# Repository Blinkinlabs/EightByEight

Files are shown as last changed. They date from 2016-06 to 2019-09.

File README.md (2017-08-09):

# EightByEight Blinky Badge
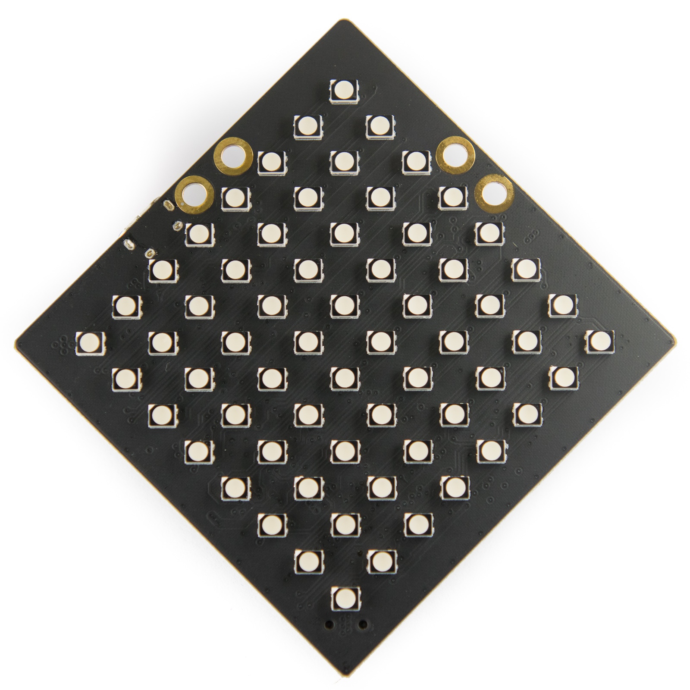
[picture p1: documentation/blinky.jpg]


EightByEight Blinky Badge, Copyright 2016 Blinkinlabs, LLC

See the ['Getting Started Guide'](https://github.com/Blinkinlabs/EightByEight/blob/master/documentation/Getting%20started%20guide.pdf) in documentation/ to learn about the badge.

Arduino examples are located in examples/.

# License

The hardware design is released under the CERN OHL v.1.2

The firmware and bootloader are released under the MIT license

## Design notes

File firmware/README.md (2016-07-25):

# EightByEight Blinky Badge

## Firmware development

The ARM toolchain 'arm-none-eabi-gcc' is used to compile this project. Specifically, the 4.8-2014-q2-update version. Get it here:

https://launchpad.net/gcc-arm-embedded/4.8/4.8-2014-q2-update

You'll also need dfu-util. Homebrew is possibly the easiest way to get this.

You'll also need GNU Make, which probably requires Xcode on OS/X, or similar developer tools on Linux. The version is probably not as important.

Note: For windows, try following steps 1 and 2 from this site to get up and running:
http://thehackerworkshop.com/?p=391

Once you have the toolchain installed, change to the firmware-gcc directory:

    cd firmware-gcc

and run make to compile:

    make

Use dfu-util (TODO: instructions for installing dfu-util!) to install the new firmware:

    make install

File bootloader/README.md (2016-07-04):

Modified Fadecandy Bootloader
=====

This is a simple open source bootloader for the Freescale Kinetis MK20DX128 microcontroller. It uses the USB Device Firmware Upgrade (DFU) standard. This bootloader was developed for use with Fadecandy, but it should be portable with to other projects using chips in the Kinetis microcontroller family, including the MK20DN64.

Installing
---

On a Teensy 3.0, you can use the Teensy Loader application to install `fc-boot.hex`. Afterwards, your Teensy should appear to the system as a "Fadecandy Bootloader" USB device capable of loading an application firmware image.

On a Fadecandy fc64x8 board, the bootloader can be installed via JTAG using OpenOCD. If you have an Olimex ARM-USB-OCD adapter, everything's already set up to install the bootloader with "make install". Other JTAG adapters will require changing `openocd.cfg`. Note: This may need to be modified to work with the LightBuddy microcontroller, specifically any sections referring to FlexRam.

Application Interface
---

This section describes the programming interface that exists between the bootloader and the application firmware.

The bootloader uses the smallest possible protected region on the MK20DX128's flash, a 4KB block. It uses a tiny amount of RAM for a "token" which is used to force entry into the bootloader on system reset.

When entering the application firmware, the system clocks will already be configured, and the watchdog timer is already enabled with a 10ms timeout. The application may disable the watchdog timer if desired.

The bootloader normally transfers control to the application early in boot, before setting up the USB controller. It will skip this step and run the DFU implementation if any of the following conditions are true:

* Both user buttons are pressed during power on (Manual recovery)
* A 32-bit entry token (0x74624346, or 'FCbt') is found at 0x2000_1FFC. (Programmatic entry)
* The application ResetVector does not reside within application flash. (No application is installed)

Memory address range       | Description
-------------------------- | ----------------------------
0x0000_0000 - 0x0000_0FFF  | Bootloader protected flash
0x0000_1000 - 0x0000_10F7  | Application IVT in flash
0x0000_1000 - 0x0001_FFFF  | Remainder of application flash
0x1FFF_E000 - 0x2000_1FFC  | Application SRAM
0x2000_1FFC - 0x2000_1FFF  | Entry token in SRAM

External Hardware
---

No external hardware is required for the bootloader to operate. The following pins are used by the bootloader for optional features:

* PD6 is a status LED, active (low) while the bootloader is in DFU mode.

File Format
---

The DFU file consists of raw 1 kilobyte blocks to be programmed into flash starting at address 0x0000_1000. The file may contain up to 63 blocks. No additional headers or checksums are included. On disk, the standard DFU suffix and CRC are used. During transit, the standard USB CRC is used.

Contact
---

Matt Mets <<matt@blinkinlabs.com>>

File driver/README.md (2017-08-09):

# Build a DFU driver for the BlinkyTile bootloader

Start with instructions here:
https://github.com/libusbx/libusbx/wiki/Windows-Backend#Driver_Installation

use this set for reference:
http://libusb-winusb-wip.googlecode.com/files/winusb%20driver.zip

Modify the 'libusb_device_multiple_interfaces_0' example to include the EightByEight runtime interface.
Modify the 'libusb_device' example to include the EightByEight interface

# Updating firmware on Windows

Get dfu-util 0.8 from the web site:
http://dfu-util.sourceforge.net/releases/dfu-util-0.8-binaries/win32-mingw32/

# Signing

Instructions based on: [http://www.davidegrayson.com/signing/](http://www.davidegrayson.com/signing/)

First, get a GlobalSign code signing signature, and install the .cer file on the machine that will be used for development.

Next, install the GlobalSign R1-R3 cross certificate on the machine. It can be obtained from here:

	https://jp.globalsign.com/support/docs/r1cross.cer

Third, download the Microsoft Globalsign Cross certificate, and place it in this driver/ directory. It can be obtained from here:

	http://go.microsoft.com/fwlink/?LinkId=321777

Finally, rrom a Windows command prompt, run the included script:

	driver_signer.bat

# Testing the signature

Use fresh VMs for various versions of Windows. If possible, do not allow the VM to connect to the internet at any point during installation or test. We test with Windows 7 Profressional 64-bit, and Windows 10 Home 32-bit. This is to ensure that the default signature for the 

It's also a good idea to test against a fully updated machine as well, if possible.

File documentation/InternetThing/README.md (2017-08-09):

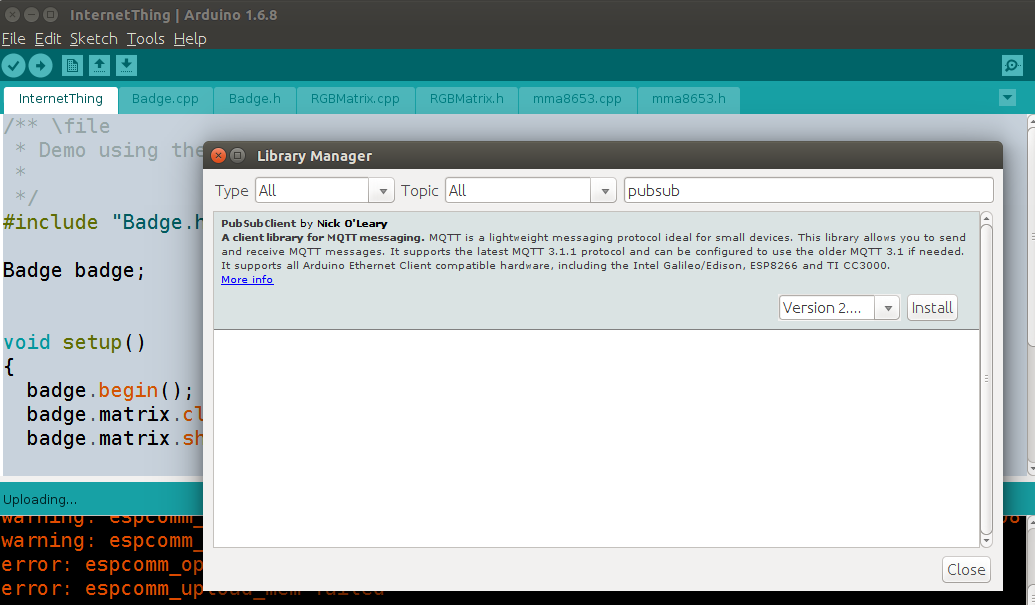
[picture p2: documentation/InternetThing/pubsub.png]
Installing PubSubClient


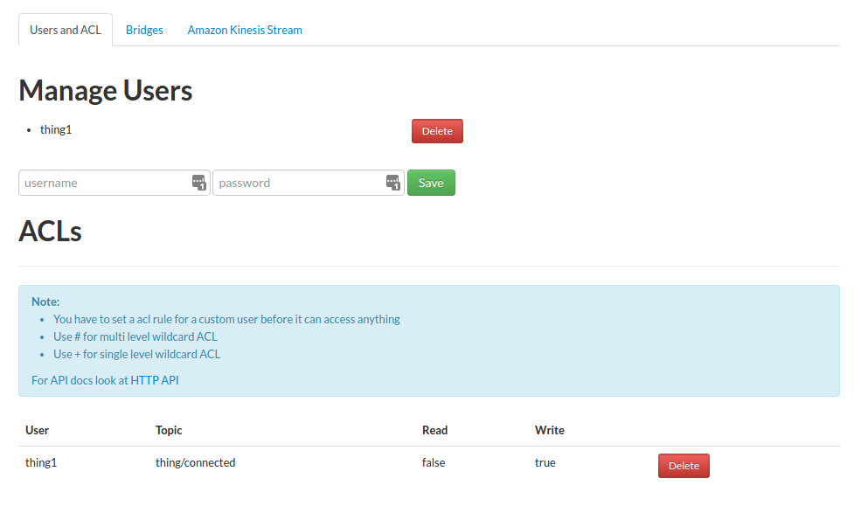
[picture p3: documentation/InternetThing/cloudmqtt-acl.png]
Setting up CloudMQTT Users and ACLs


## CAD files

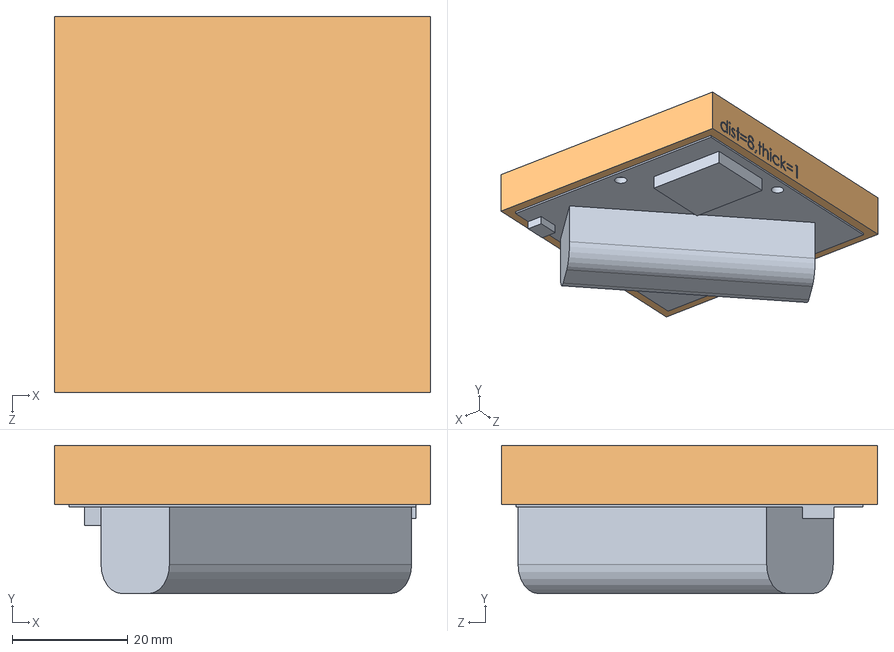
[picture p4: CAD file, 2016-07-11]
concept design/assembled case.SLDASM
65.0 x 25.6 x 65.0 mm
60mm diamond
blank case

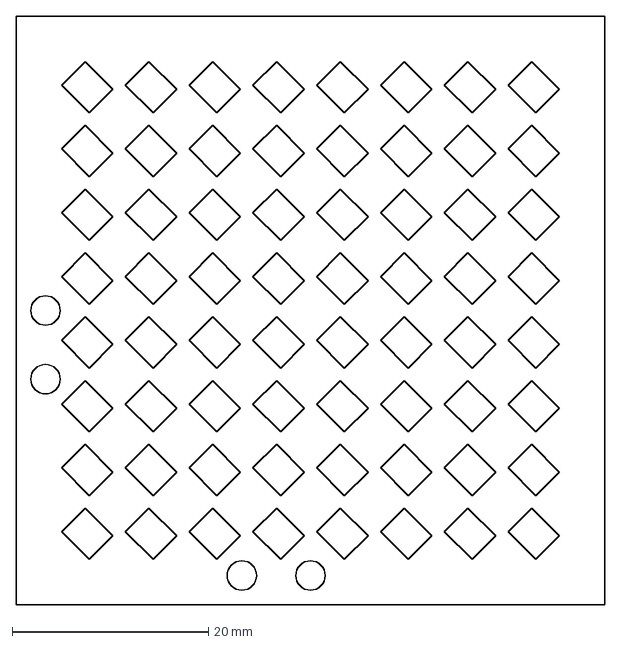
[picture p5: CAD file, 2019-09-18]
documentation/eightbyeight_template.dxf
60.0 x 60.0 mm

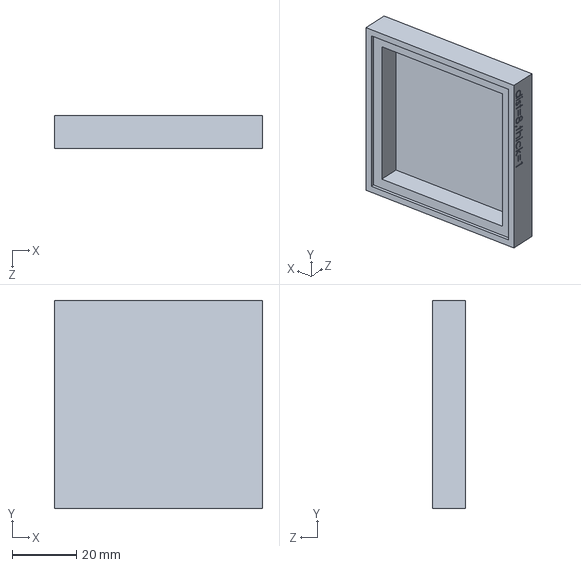
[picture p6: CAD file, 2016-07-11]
concept design/blank case.sldprt
65.0 x 65.0 x 10.2 mm

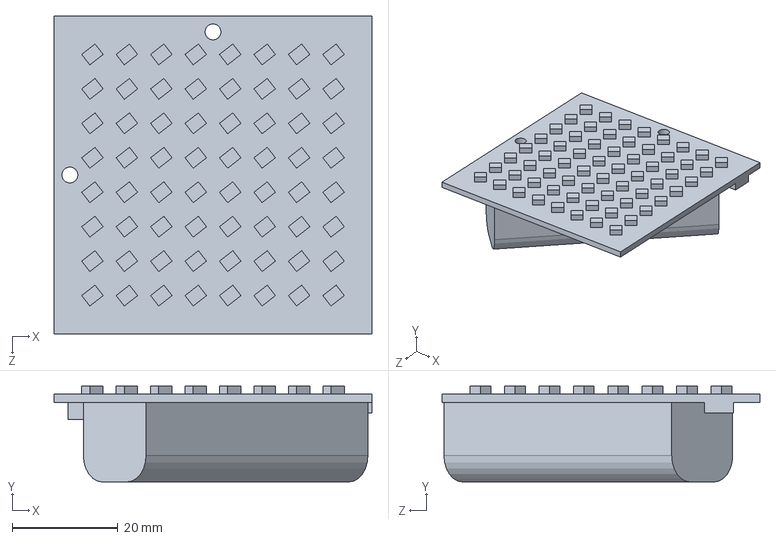
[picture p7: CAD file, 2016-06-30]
concept design/60mm diamond.SLDPRT
60.0 x 18.1 x 60.0 mm

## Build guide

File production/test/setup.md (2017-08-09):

# EightByEight Blinky Test Program

The factory test uses a Raspberry Pi 

Setup instructions for 'Raspbian Jessie Lite'

# Set a unique hostname

	echo 'testrig-003' | sudo tee /etc/hostname

# Get the system up to date

	sudo apt-get update
	sudo apt-get install build-essential git libtool automake libusb-1.0.0-dev python-smbus python-serial i2c-tools python3-gpiozero python-gpiozero vim screen telnet python3 python3-pip python-dev python-pip gcc-arm-none-eabi dfu-util

# Enable I2c, disable serial

	sudo raspi-config

then:
	
	Select '9 Advanced Options'
	Select 'A6 I2C'
	Select 'yes'
	Select '9 Advanced Options'
	Select 'A? Serial'
	Select 'no'
	Select yes to reboot now

# Configure the RTC (not working?)

	sudo su
	modprobe rtc-ds1307
	echo ds1307 0x68 > /sys/class/i2c-adapter/i2c-1/new_device

	sudo hwclock -w

	sudo nano /etc/modules
	
add:

	rtc-ds1307
	i2c_bcm2708

vi  /lib/systemd/system/rtc-i2c.service

	[init]
	Description=Initialize i2c hardware RTC device driver
	DefaultDependencies=no
	Requires=systemd-modules-load.service
	After=systemd-modules-load.service
	Before=sysvinit.target
	ConditionPathExists=/sys/class/i2c-adapter
	Conflicts=shutdown.target
	
	[Service]
	Type=oneshot
	RemainAfterExit=yes
	EnvironmentFile=/etc/conf.d/rtc-i2c
	ExecStart=/bin/sh -c "echo ${CHIP} ${ADDRESS} > /sys/class/i2c-adapter/i2c-${BUS}/new_device"
	
	[Install]
	WantedBy=sysinit.target

mkdir /etc/conf.d
vi /etc/conf.d/rtc-i2c

	# /etc/conf.d/rtc-i2c
	CHIP="ds1307"
	ADDRESS="0x68"
	BUS="1"

then:

	sudo systemctl enable rtc-i2c.service 
	sudo apt-get remove fake-hwclock 

	sudo update-rc.d -f fake-hwclock remove 

# Configure a wifi hotspot

Follow: https://frillip.com/using-your-raspberry-pi-3-as-a-wifi-access-point-with-hostapd/

	ap: twosigma-blinky
	pw: blinkblinkblink

# Install dfu (optional)

TODO: We actually need .7 :-(

Install from git, since we need version .9 (why?)

	git clone git://git.code.sf.net/p/dfu-util/dfu-util
	cd dfu-util
	./autogen.sh
	./configure
	make
	sudo make install

# Install openocd

	git clone git://git.code.sf.net/p/openocd/code openocd-code
	cd openocd-code/
	git checkout 406f4d1c68330e3bf8d9db4e402fd8802a5c79e2	
make this modification:

	diff --git a/src/flash/nor/kinetis.c b/src/flash/nor/kinetis.c
	index aed37b9..8ab4c11 100644
	--- a/src/flash/nor/kinetis.c
	+++ b/src/flash/nor/kinetis.c
	@@ -1479,6 +1479,9 @@ static int kinetis_probe(struct flash_bank *bank)
	        }
	 
	        /* when the PFLSH bit is set, there is no FlexNVM/FlexRAM */
	+
	+       fcfg2_pflsh = true;
	+
	        if (!fcfg2_pflsh) {
	                switch (fcfg1_nvmsize) {
	                case 0x03:
                
then:

	./bootstrap
	./configure --enable-sysfsgpio --enable-bcm2835gpio --enable-ftdi
	make
	sudo make install

# Install esptool

git clone https://github.com/themadinventor/esptool.git

# Install python libs

	sudo pip install Adafruit-GPIO adafruit-ads1x15

# Install this repository

	git clone https://github.com/Blinkinlabs/EightByEight.git

# Fix monitor resolution

Only needed for 8" hdmi monitor

sudo vi /boot/config.txt

	# force 800x600
	hdmi_group=2
	hdmi_mode=9
	display_rotate=3

# Configure to start at boot

Run in the terminal:

	vi ~/.bashrc

Add add to the end:

	if [ -z "$SSH_CLIENT" ]; then
		setterm -blank 0
		clear
		cd /home/pi/EightByEight/production/test/; sudo ./run-eightbyeight-tests.sh
	fi

And set up the rgbw test pattern generator:

	sudo cp spamrgb.service /etc/systemd/system
	sudo systemctl enable spamrgb.service

# Rejoice!

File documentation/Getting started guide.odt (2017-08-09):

EightByEight Blinky Badge

Users Guide

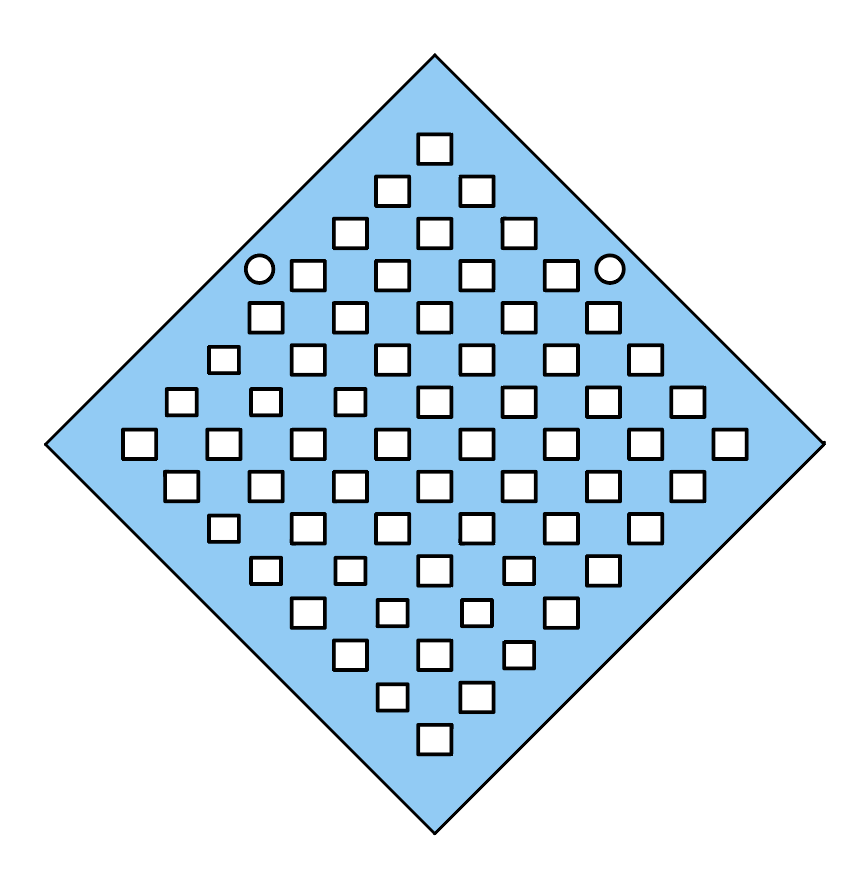
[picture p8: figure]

# Programming the ESP8266

## Windows only: Install the drivers

The eightbyeight badge acts USB CDC device, and requires a simple driver.

## Getting Started with Arduino

1. Follow the setup instructions for ESP8266 on Arduino:

https://github.com/esp8266/Arduino/blob/master/README.md

2. Use the following settings to connect to the board:

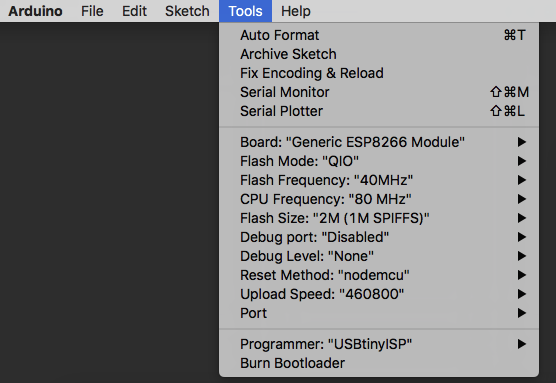
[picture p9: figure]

Note that only a baud rate of 460800 is currently supported. The ARM part emulates the ‘nodemcu’ method for resetting the ESP chip.

3. Load the example sketch and upload it. If all goes well, the LEDs on the badge should start showing a color pattern. You’re ready to go!

## ESP pin assignments

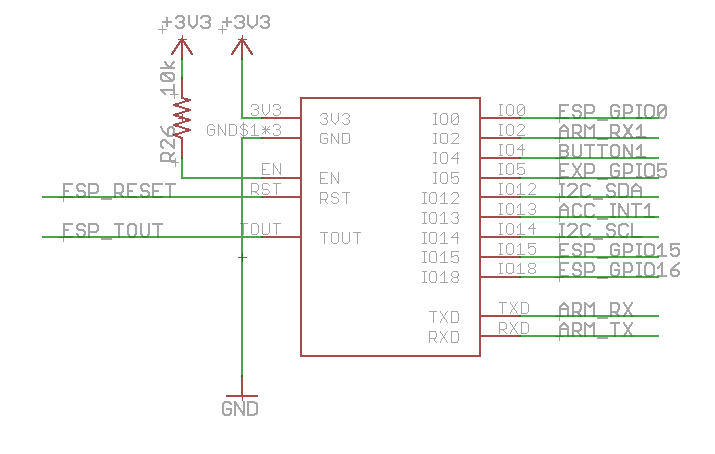
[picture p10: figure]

## Controlling the LEDs

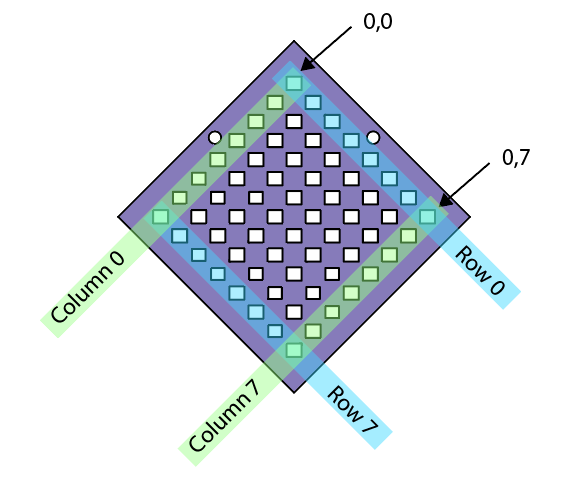
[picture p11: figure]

TODO: Encapsulate this into a library, expose functions to change display brightness, speed (see matrix_setPixelColor() and matrix_show() functions in the BadgeDemo sketch)

The LEDs are controlled by sending data to the serial1 port on the ESP8266 chip. The ARM chip does the busy work of generating the PWM signals, and supports a simple serial protocol for updating the LEDs.

For each LED, you’ll need to send an 8-bit value for the red, green, and blue brightness. The eight bit value can vary from 0 (fully off) to 254 (fully on). There are 64 LEDs, so

Note: Internally, the matrix driver expands this to a brightness corrected, 11-bit space. (TODO: More bits)

First, initialize the port with a baud rate of 230400:

Serial1.begin( 230400 );

Next, send the data for each LED (this example sets the entire display to red):

for(int i = 0; i < 64; i++) {

Serial1.print(char(255)); // Red

Serial1.print(char(0)); // Green

Serial1.print(char(0)); // Blue

}

Finally, send a ‘255’ character to tell the matrix to start displaying the new data:

Serial1.print(char(255));

## Reading the button

There is a single button on the badge, that does nothing by default. It is connected to GPIO pin 4 on the ESP8266 wifi chip.

To read the status, first put the pin in input mode:

const int button = 4;

pinMode(button, INPUT_PULLUP);

Then, the button status can be read using the digitalRead() function:

bool buttonPressed = !digitalRead(button);

Note that the value of the button input is low when the button is pressed, and high when it is not pressed.

## Reading accelerometer data

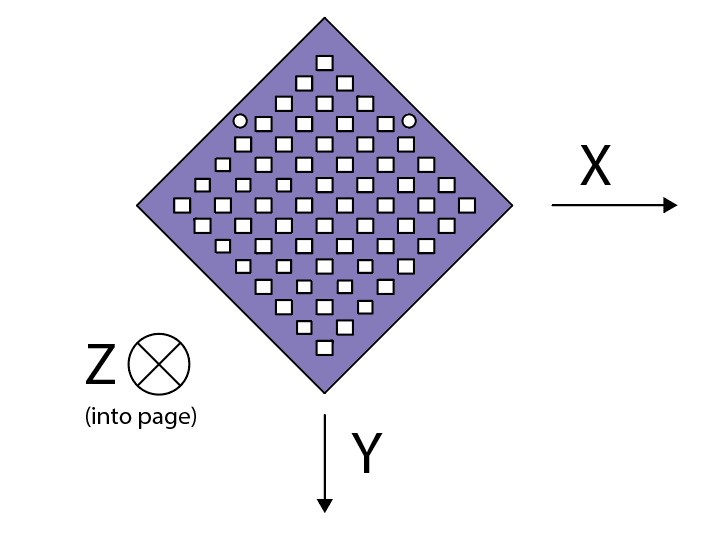
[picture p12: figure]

The accelerometer is connected to the ESP using an I2C bus. The ESP doesn’t actually have a hardware I2C peripheral, however the ROM can emulate one. First, set up the Wire library to start the I2C bus:

const int i2c_scl = 14;

const int i2c_sda = 12;

Wire.begin(i2c_sda, i2c_scl);

after Wire is configured correctly, set up the mma8653 library:

mma8653.setup();

Once everything is configured correctly, the most current values can be read from the accelerometer:

float x, y, z;

mma8653.getXYZ(x, y, z);

TODO: Implement interrupt to automatically poll accelerometer data, implement implement accessor functions for individual axis data to avoid references in function call.

# System Diagram

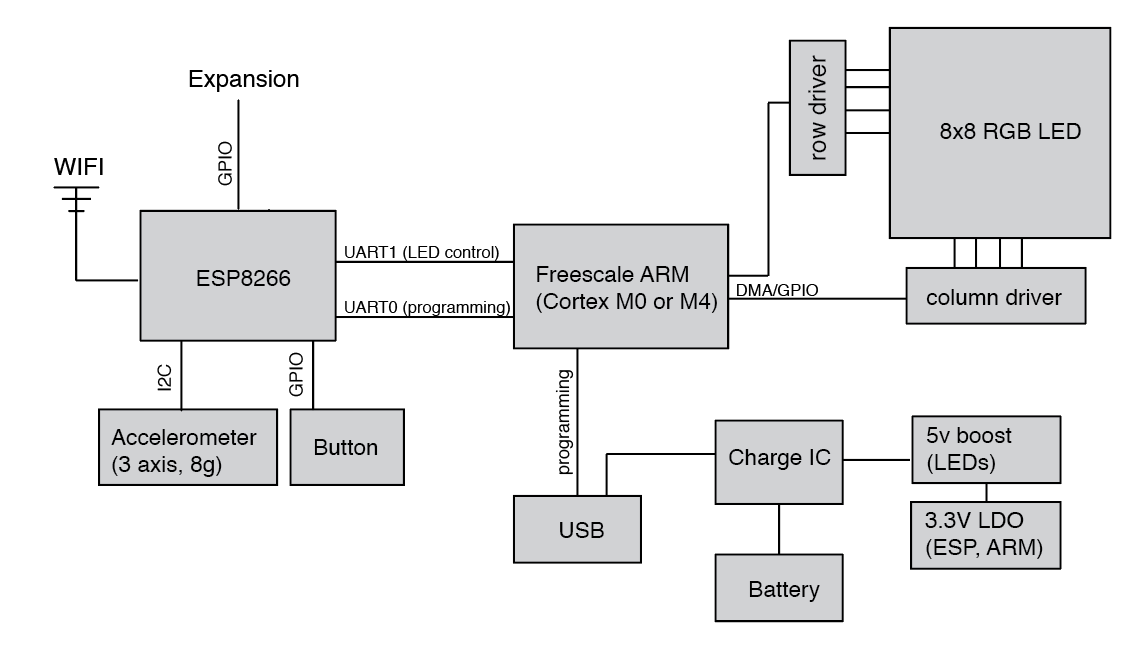
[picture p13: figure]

Everything fits together like this!

# Updating the ARM firmware

The ARM chip acts as a USB-to-Serial converter for the ESP8266 Wifi module, and as a sophisticated LED controller for the 8x8 RGB LED matrix. The firmware should normally not need to be upgraded, however it supports the DFU protocol for loading new firmware.

TODO: Directions for updating firmware (see: https://github.com/Blinkinlabs/BlinkyTile/tree/master/firmware)

TODO: Directions for entering firmware recovery mode using test pin.

Copyright 2016 Blinkinlabs, LLC

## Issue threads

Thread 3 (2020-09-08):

No USB serial ports showing up for board

benjaminbradley, 2020-09-08:
I upgraded my Mac OS and then it could no longer see the 8x8 board on the Arduino app's Ports menu when I plugged it in.
It turns out that:

> Yosemite 10.9 (and OS X 10.10 and newer) requires a signed USB driver kext (kernel extension). You can find one on the FTDI web site here: http://www.ftdichip.com/Drivers/VCP.htm
> Use version 2.3 [or the latest version-Ed] for 64-bit OS X 10.9 or later. Install and reboot.
ref: https://arduino.stackexchange.com/a/13825

Adding here in case any other 8x8 users run into this issue as well.

cibomahto, 2020-09-08:
Interesting- the EightByEight uses an ARM part as a USB to serial converter, so it shouldn't have anything to do with the FTDI driver.

benjaminbradley, 2020-09-15:
Hmm my usbserialmodem has disappeared again, so it seems the FTDI driver may have been unrelated. Thinking that it was the reboot that fixed it before, I tried that again, but it's still not showing up. LMK if you have any tips! I'm running:
* Mac OS 10.15.1
* Arduino 1.8.13
* ESP8266 Boards 2.5.0 (downgraded based on https://forum.arduino.cc/index.php?topic=622116.msg4414063#msg4414063 )

I'm using the same USB cable that was working a week ago, and it is getting power. I've tried both USB ports available.

cibomahto, 2020-09-21:
First, make sure the power switch on the board is set to the on position. The other suggestion would be to try plugging it into a USB hub, rather than directly into your computer.

benjaminbradley, 2020-09-21:
The USB hub fixed it!

Closed 2020-09-21.

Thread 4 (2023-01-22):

Cannot upload from Arduino IDE 2.0.3 and esp8266 3.1.1

rgov, 2023-01-22:
I'm running macOS 13.1 and Arduino IDE 2.0.3 with esp8266 version 3.1.1.

I've configured the Arduino IDE according to the Getting Started document, or as close as I can given that the IDE is a little different now.

When I reset the board and then press "Upload", it eventually fails with:

```
esptool.py v3.0
Serial port /dev/cu.usbmodem32123101
Connecting........_____.
A fatal esptool.py error occurred: Timed out waiting for packet header
Chip is ESP8266EX
Features: WiFi
WARNING: Detected crystal freq 6.62MHz is quite different to normalized freq 26MHz. Unsupported crystal in use?
Crystal is 26MHz
MAC: a0:20:a6:01:22:a5
Uploading stub...
Running stub...
Stub running...
Changing baud rate to 460800
Changed.
Configuring flash size...
```

cibomahto, 2023-01-26:
I can repeat this with Arduino 2.0.3 and esp8266 3.1.1 on a Windows machine.

I was able to get it working by changing the esp8266 version to 2.7.4, and uploading the 'blinkydemo' sketch with the following settings:
board: generic esp8266 module
reset method: nodemcu
upload speed: 512000

Can you try these settings and see if they work for you?

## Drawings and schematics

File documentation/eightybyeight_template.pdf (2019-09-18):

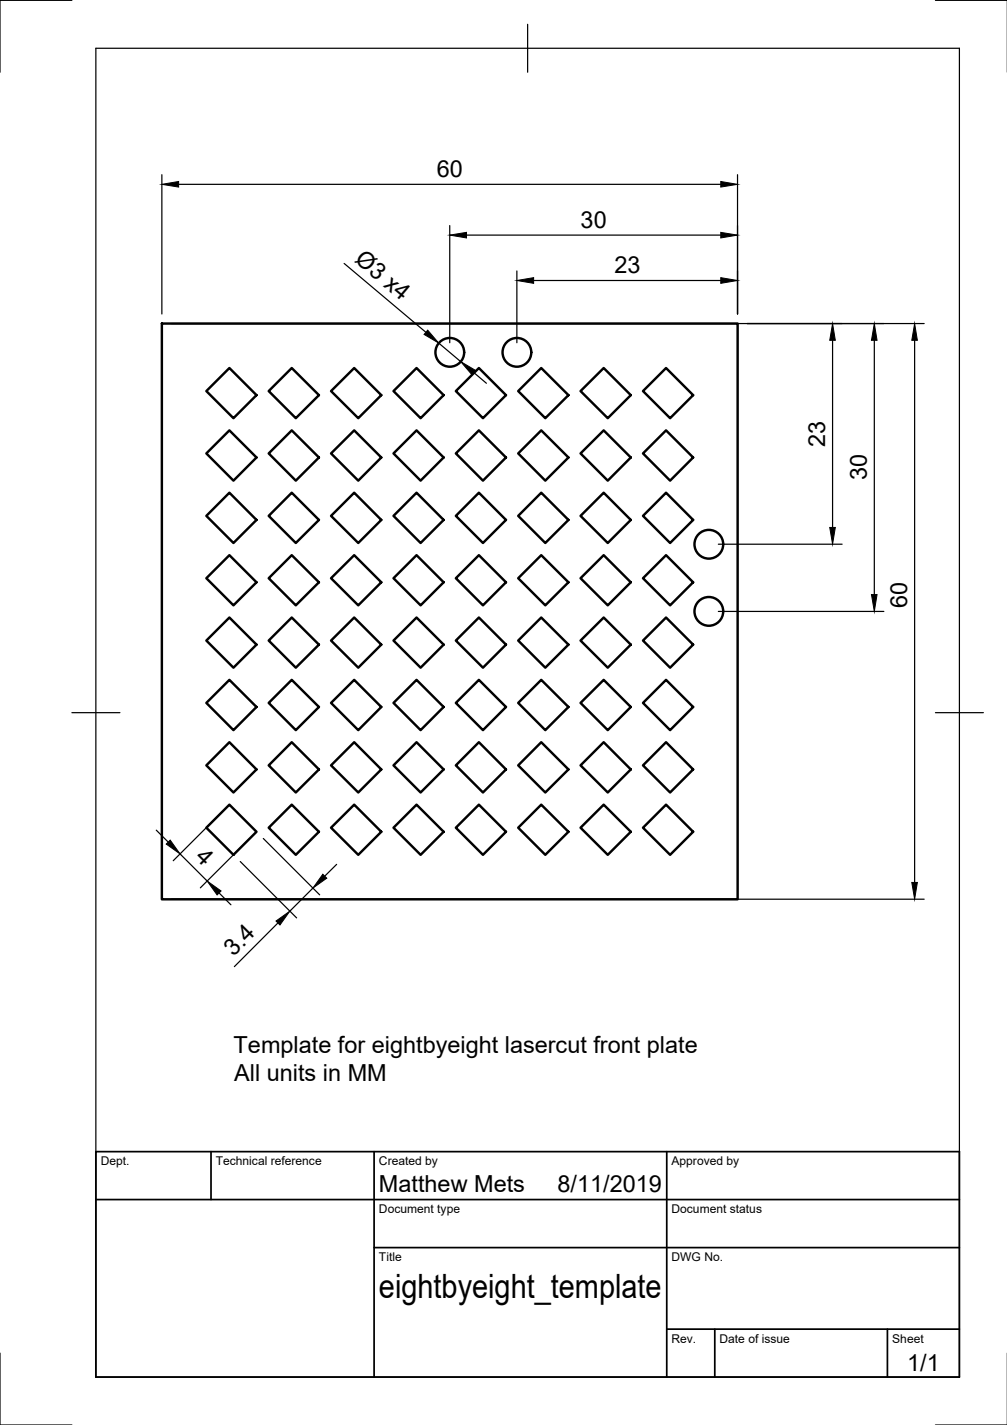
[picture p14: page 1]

Template for eightbyeight lasercut front plate
All units in MM

Dept. | Technical reference | Created by Matthew Mets 8/11/2019 | Approved by

Document type | Document status

Title eightbyeight_template | DWG No.

Rev. | Date of issue | Sheet 1/1

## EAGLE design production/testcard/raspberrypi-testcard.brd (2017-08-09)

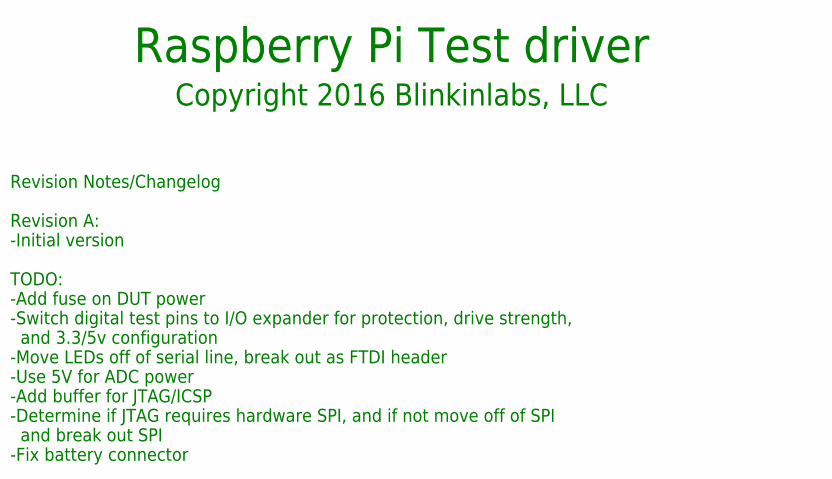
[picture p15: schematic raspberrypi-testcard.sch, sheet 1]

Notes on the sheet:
Revision Notes/Changelog Revision A: -Initial version TODO: -Add fuse on DUT power -Switch digital test pins to I/O expander for protection, drive strength, and 3.3/5v configuration -Move LEDs off of serial line, break out as FTDI header -Use 5V for ADC power -Add buffer for JTAG/ICSP -Determine if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
Raspberry Pi Test driver
Copyright 2016 Blinkinlabs, LLC

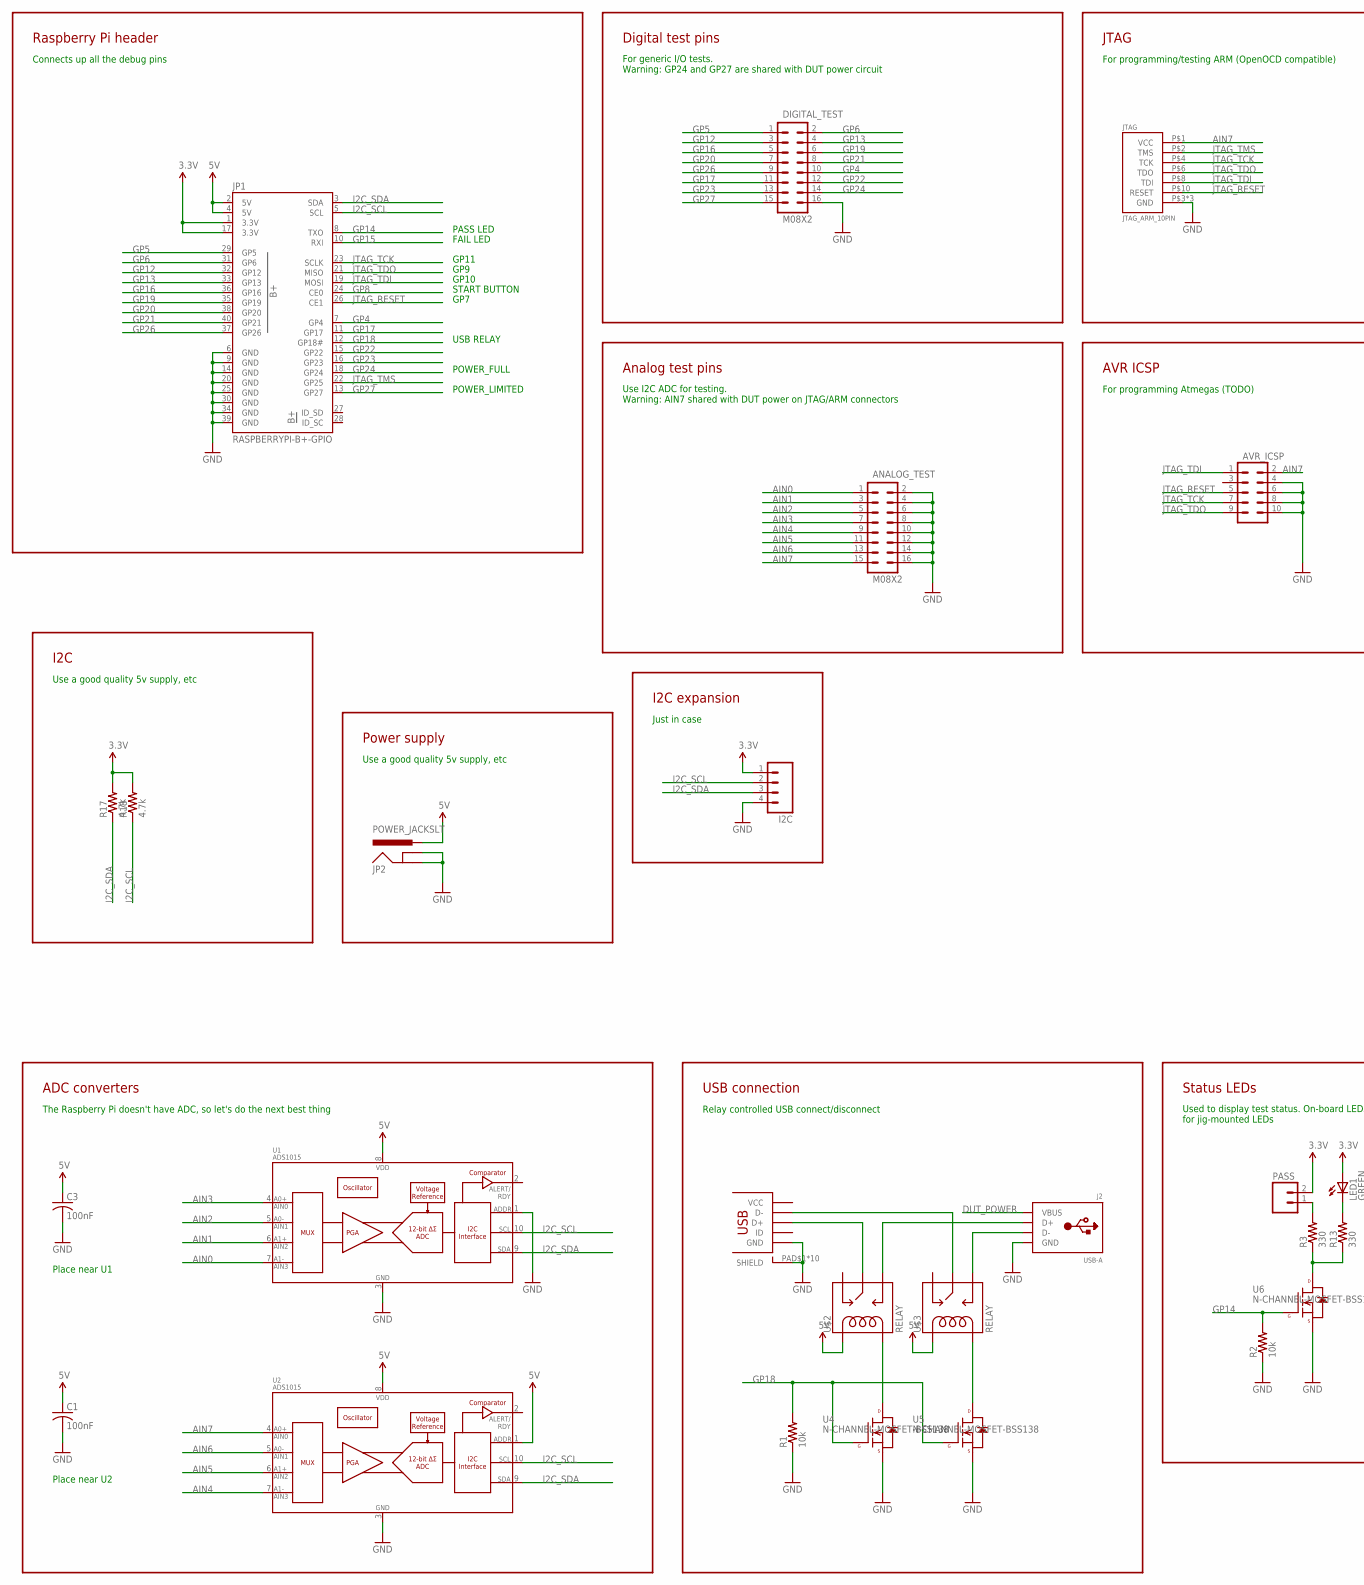
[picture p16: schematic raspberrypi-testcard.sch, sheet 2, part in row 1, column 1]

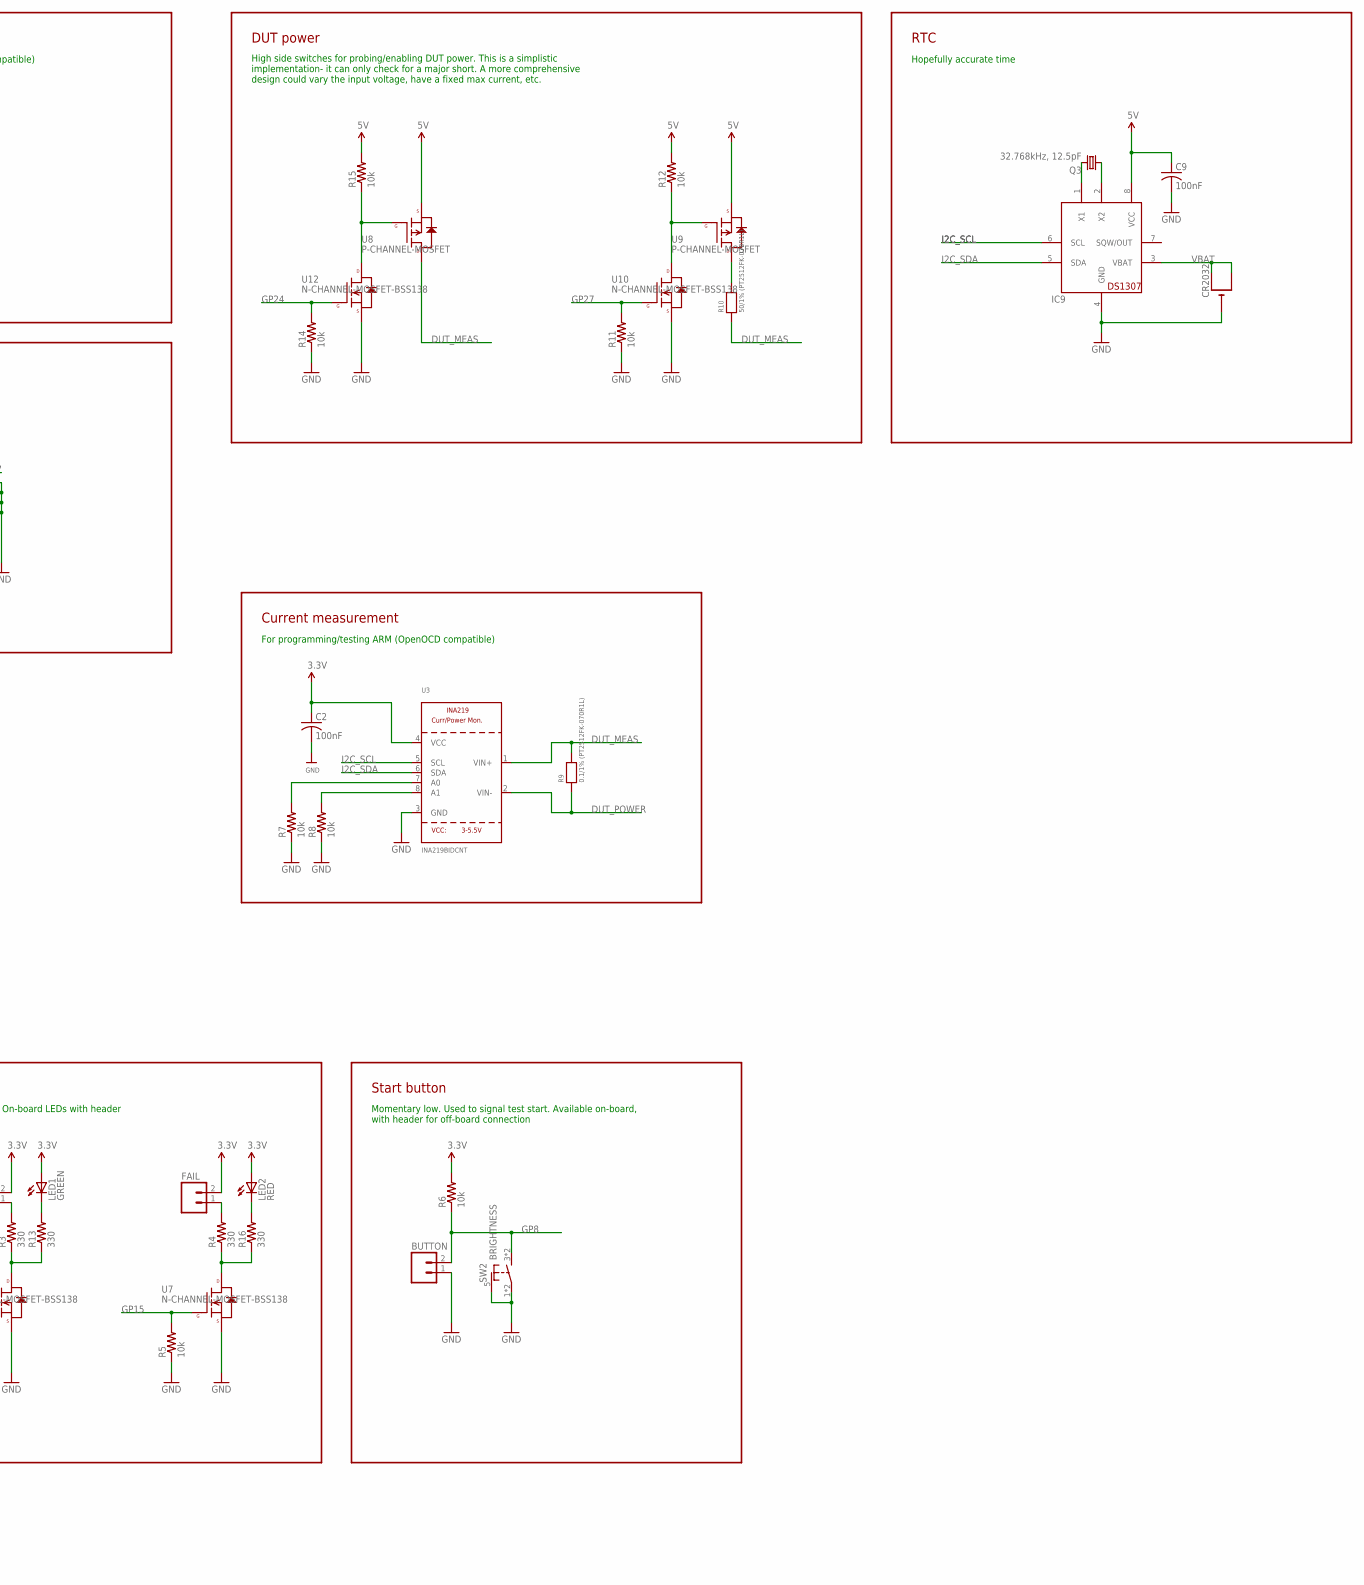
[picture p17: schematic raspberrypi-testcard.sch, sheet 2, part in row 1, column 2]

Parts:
ANALOG_TEST: M08X2; 2X8
AVR_ICSP: M05X2PTH; AVR_ICSP
BUTTON: M02JST-PTH-2; JST-2-PTH
C1, C2, C3: 100nF; C0402
C9: 100nF; C0402K
CR2032: CR2032SMT; CR2032-SMD
DIGITAL_TEST: M08X2; 2X8
FAIL: M02JST-PTH-2; JST-2-PTH
I2C: M04PTH; 1X04
IC9: DS1307SO08; SO08-150
J1: USB_MICROSMT+THRUHULE; USB_MICRO_THRUHOLE
J2: USB-A; MOLEX_480371000
JP1: RASPBERRYPI-B+-GPIO; 2X20-SHROUDED
JP2: POWER_JACKSLT; POWER_JACK_SLOT
JTAG: JTAG_ARM_10PIN; 2X05-1.27MM-SMD
LED1: GREEN; CHIP-LED0805
LED2: RED; CHIP-LED0805
PASS: M02JST-PTH-2; JST-2-PTH
Q3: 32.768kHz, 12.5pF; TC26H
R1, R2, R5, R6, R7, R8, R11, R12, R14, R15: 10k; R0402
R3, R4, R13, R16: 330; R0402
R9: 0.1/1% (PT2512FK-070R1L); 2512
R10: 50/1% (PT2512FK-070R1L); 2512
R17, R18: 4.7k; R0402
SW2: BRIGHTNESS; TD-07XB
U1, U2: ADS1015; MSOP10
U3: INA219BIDCNT; SOT23-8
U4, U5, U6, U7, U10, U12: N-CHANNEL-MOSFET-BSS138; SOT23-3
U8, U9: P-CHANNEL-MOSFET; SOT23-3
U$2, U$3: RELAY; RELAY_HK23F-5V

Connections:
3.3V: C2.1, FAIL.2, I2C.1, JP1.1 (3.3V), JP1.17 (3.3V), LED1.A, LED2.A, PASS.2, R6.2, R17.2, R18.2, U3.4 (VCC)
5V: C1.1, C3.1, C9.1, IC9.8 (VCC), JP1.2 (5V), JP1.4 (5V), JP2.PWR, R12.2, R15.2, U1.8 (VDD), U2.1 (ADDR), U2.8 (VDD), U8.2 (S), U9.2 (S), U$2.P$2 (COIL1), U$3.P$2 (COIL1)
AIN0: ANALOG_TEST.1, U1.7 (AIN3)
AIN1: ANALOG_TEST.3, U1.6 (AIN2)
AIN2: ANALOG_TEST.5, U1.5 (AIN1)
AIN3: ANALOG_TEST.7, U1.4 (AIN0)
AIN4: ANALOG_TEST.9, U2.7 (AIN3)
AIN5: ANALOG_TEST.11, U2.6 (AIN2)
AIN6: ANALOG_TEST.13, U2.5 (AIN1)
AIN7: ANALOG_TEST.15, AVR_ICSP.2, JTAG.P$1 (VCC), U2.4 (AIN0)
DUT_MEAS: R9.2, R10.1, U3.1 (VIN+), U8.3 (D)
DUT_POWER: J2.1 (VBUS), R9.1, U3.2 (VIN-)
GND: ANALOG_TEST.2, ANALOG_TEST.4, ANALOG_TEST.6, ANALOG_TEST.8, ANALOG_TEST.10, ANALOG_TEST.12, ANALOG_TEST.14, ANALOG_TEST.16, AVR_ICSP.4, AVR_ICSP.6, AVR_ICSP.8, AVR_ICSP.10, BUTTON.1, C1.2, C2.2, C3.2, C9.2, CR2032.-, DIGITAL_TEST.16, I2C.4, IC9.4 (GND), J1.PAD$1 (SHIELD), J1.PAD$2 (SHIELD), J1.PAD$3 (SHIELD), J1.PAD$4 (SHIELD), J1.PAD$5 (SHIELD), J1.PAD$6 (SHIELD), J1.PAD$7 (SHIELD), J1.PAD$8 (SHIELD), J1.PAD$9 (SHIELD), J1.PAD$10 (SHIELD), J1.PIN$5 (GND), J2.4 (GND), JP1.6 (GND), JP1.9 (GND), JP1.14 (GND), JP1.20 (GND), JP1.25 (GND), JP1.30 (GND), JP1.34 (GND), JP1.39 (GND), JP2.GND@1 (GNDBREAK), JP2.GND@2 (GND), JTAG.P$3 (GND), JTAG.P$5 (GND), JTAG.P$9 (GND), R1.1, R2.1, R5.1, R7.1, R8.1, R11.1, R14.1, SW2.1, SW2.2, SW2.5 (SHIELD), U1.1 (ADDR), U1.3 (VSS), U2.3 (VSS), U3.3 (GND), U4.2 (S), U5.2 (S), U6.2 (S), U7.2 (S), U10.2 (S), U12.2 (S)
GP4: DIGITAL_TEST.10, JP1.7 (GP4)
GP5: DIGITAL_TEST.1, JP1.29 (GP5)
GP6: DIGITAL_TEST.2, JP1.31 (GP6)
GP8: BUTTON.2, JP1.24 (CE0), R6.1, SW2.3 (S), SW2.4 (S)
GP12: DIGITAL_TEST.3, JP1.32 (GP12)
GP13: DIGITAL_TEST.4, JP1.33 (GP13)
GP14: JP1.8 (TXO), R2.2, U6.1 (G)
GP15: JP1.10 (RXI), R5.2, U7.1 (G)
GP16: DIGITAL_TEST.5, JP1.36 (GP16)
GP17: DIGITAL_TEST.11, JP1.11 (GP17)
GP18: JP1.12 (GP18#), R1.2, U4.1 (G), U5.1 (G)
GP19: DIGITAL_TEST.6, JP1.35 (GP19)
GP20: DIGITAL_TEST.7, JP1.38 (GP20)
GP21: DIGITAL_TEST.8, JP1.40 (GP21)
GP22: DIGITAL_TEST.12, JP1.15 (GP22)
GP23: DIGITAL_TEST.13, JP1.16 (GP23)
GP24: DIGITAL_TEST.14, JP1.18 (GP24), R14.2, U12.1 (G)
GP26: DIGITAL_TEST.9, JP1.37 (GP26)
GP27: DIGITAL_TEST.15, JP1.13 (GP27), R11.2, U10.1 (G)
I2C_SCL: I2C.2, IC9.6 (SCL), JP1.5 (SCL), R18.1, U1.10 (SCL), U2.10 (SCL), U3.5 (SCL)
I2C_SDA: I2C.3, IC9.5 (SDA), JP1.3 (SDA), R17.1, U1.9 (SDA), U2.9 (SDA), U3.6 (SDA)
JTAG_RESET: AVR_ICSP.5, JP1.26 (CE1), JTAG.P$10 (RESET)
JTAG_TCK: AVR_ICSP.7, JP1.23 (SCLK), JTAG.P$4 (TCK)
JTAG_TDI: AVR_ICSP.1, JP1.19 (MOSI), JTAG.P$8 (TDI)
JTAG_TDO: AVR_ICSP.9, JP1.21 (MISO), JTAG.P$6 (TDO)
JTAG_TMS: JP1.22 (GP25), JTAG.P$2 (TMS)
unnamed: J1.PIN$3 (D+), U$2.P$1 (MAIN), U$2.P$6 (MAIN)
unnamed: J2.3 (D+), U$2.P$3 (NO)
unnamed: J1.PIN$2 (D-), U$3.P$1 (MAIN), U$3.P$6 (MAIN)
unnamed: J2.2 (D-), U$3.P$3 (NO)
unnamed: R4.1, R16.1, U7.3 (D)
unnamed: U5.3 (D), U$3.P$5 (COIL2)
unnamed: U4.3 (D), U$2.P$5 (COIL2)
unnamed: R3.1, R13.1, U6.3 (D)
unnamed: R8.2, U3.8 (A1)
unnamed: FAIL.1, R4.2
unnamed: PASS.1, R3.2
unnamed: R7.2, U3.7 (A0)
unnamed: R10.2, U9.3 (D)
unnamed: R12.1, U9.1 (G), U10.3 (D)
unnamed: LED2.C, R16.2
unnamed: R15.1, U8.1 (G), U12.3 (D)
unnamed: LED1.C, R13.2
unnamed: IC9.1 (X1), Q3.2
unnamed: IC9.2 (X2), Q3.1
VBAT: CR2032.+$1 (+), CR2032.+$2 (+1), IC9.3 (VBAT)

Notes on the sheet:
Connects up all the debug pins
Raspberry Pi header
For generic I/O tests. Warning: GP24 and GP27 are shared with DUT power circuit
Digital test pins
Use I2C ADC for testing. Warning: AIN7 shared with DUT power on JTAG/ARM connectors
Analog test pins
For programming/testing ARM (OpenOCD compatible)
JTAG
For programming Atmegas (TODO)
AVR ICSP
The Raspberry Pi doesn't have ADC, so let's do the next best thing
ADC converters
USB connection
Relay controlled USB connect/disconnect
Power supply
Use a good quality 5v supply, etc
Place near U1
Place near U2
I2C
Status LEDs
Used to display test status. On-board LEDs with header for jig-mounted LEDs
Start button
Momentary low. Used to signal test start. Available on-board, with header for off-board connection
Just in case
I2C expansion
Current measurement
High side switches for probing/enabling DUT power. This is a simplistic implementation- it can only check for a major short. A more comprehensive design could vary the input voltage, have a fixed max current, etc.
DUT power
Hopefully accurate time
RTC
GP11
GP9
GP10
GP7
START BUTTON
USB RELAY
PASS LED
FAIL LED
POWER_LIMITED
POWER_FULL

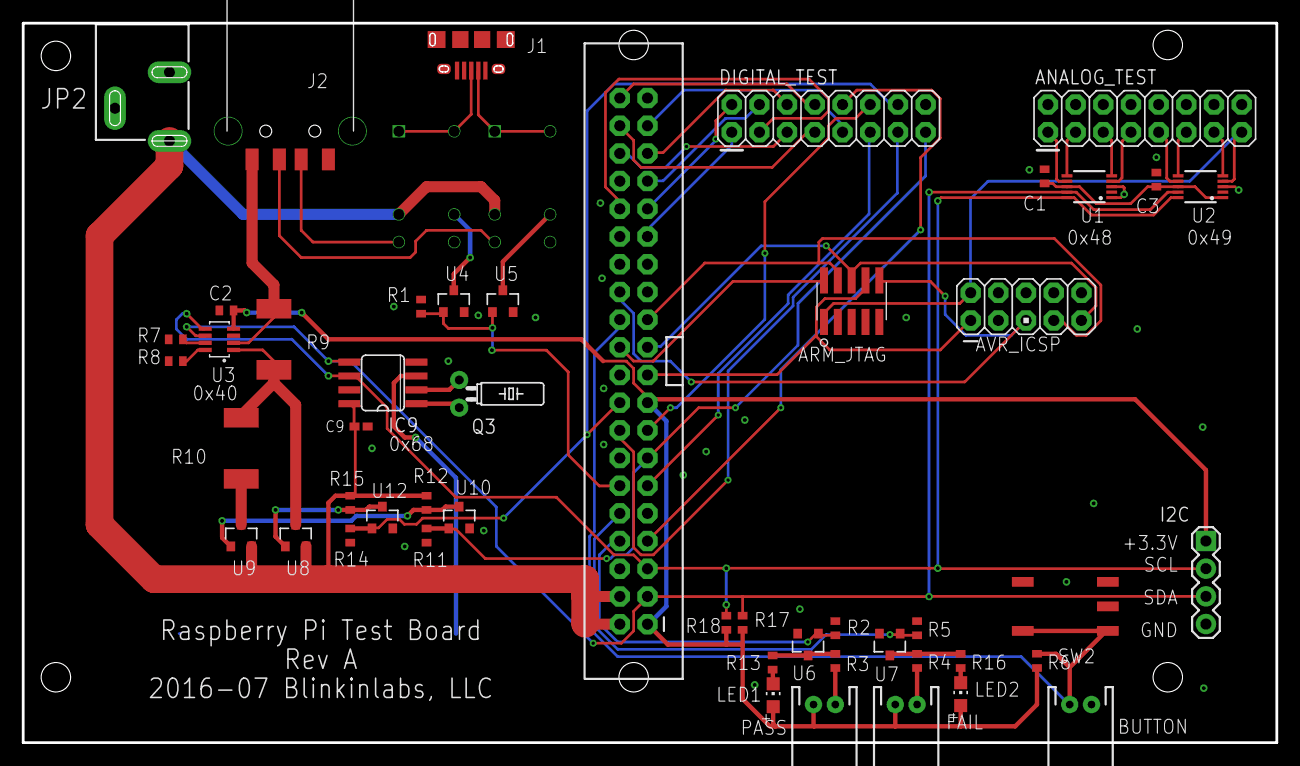
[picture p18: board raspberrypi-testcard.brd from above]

Board: 2 copper layers, 115.0 x 66.0 mm, 53 parts (1 on the bottom side), 59 nets.

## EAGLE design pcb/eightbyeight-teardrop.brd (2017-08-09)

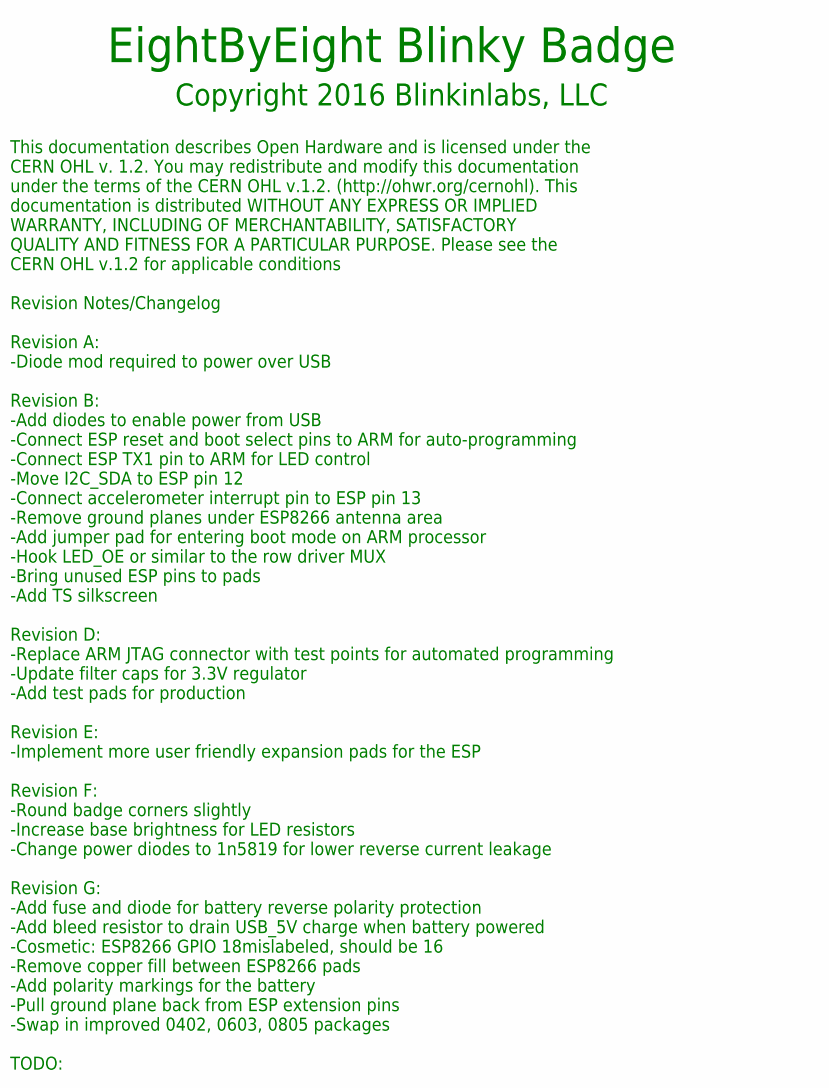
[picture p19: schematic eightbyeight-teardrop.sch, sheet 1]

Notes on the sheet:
Revision Notes/Changelog Revision A: -Diode mod required to power over USB Revision B: -Add diodes to enable power from USB -Connect ESP reset and boot select pins to ARM for auto-programming -Connect ESP TX1 pin to ARM for LED control -Move I2C_SDA to ESP pin 12 -Connect accelerometer interrupt pi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
EightByEight Blinky Badge
Copyright 2016 Blinkinlabs, LLC
This documentation describes Open Hardware and is licensed under the CERN OHL v. 1.2. You may redistribute and modify this documentation under the terms of the CERN OHL v.1.2. (http://ohwr.org/cernohl). This documentation is distributed WITHOUT ANY EXPRESS OR IMPLIED WARRANTY, INCLUDING OF MERCHANT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

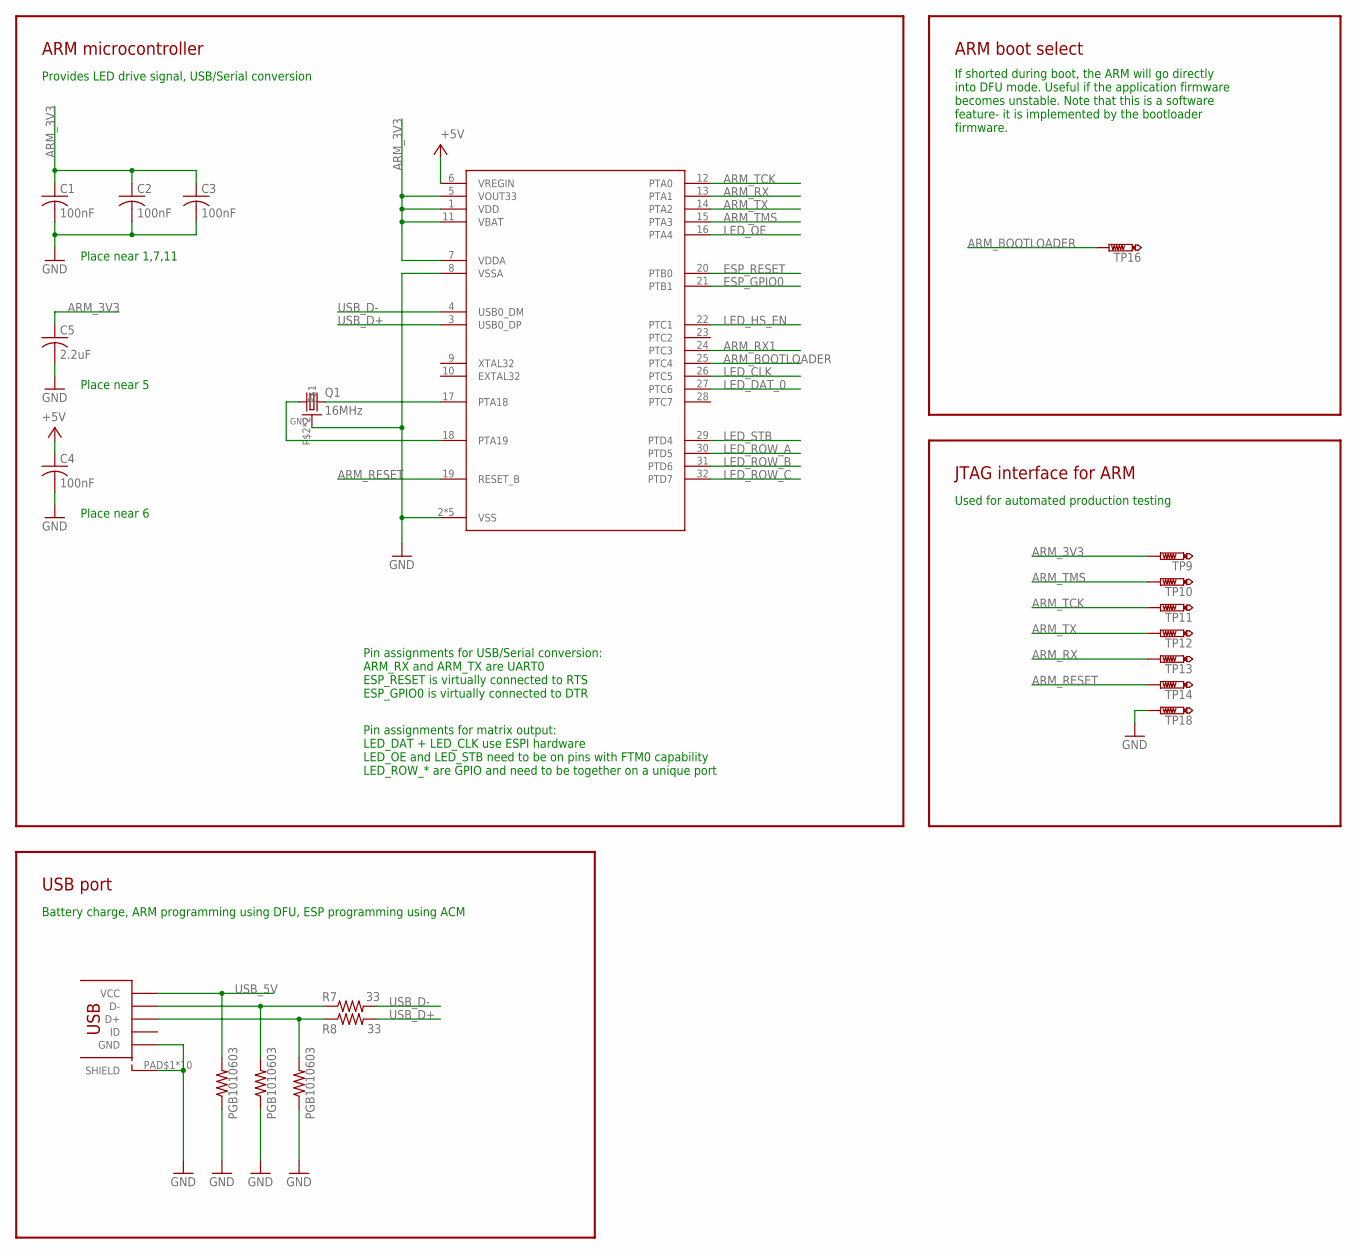
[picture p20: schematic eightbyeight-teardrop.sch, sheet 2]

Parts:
C1, C2, C3, C4: 100nF; CAP_0402
C5: 2.2uF; CAP_0402
J1: USB_MICROSMT+THRUHULE; USB_MICRO_THRUHOLE
Q1: 16MHz; CRSYTAL_2520
R7, R8: 33; R_0402
TP9, TP10, TP11, TP12, TP13, TP14, TP16, TP18: PTR1B1,27; B1,27
U1: MK20DN64VFM5; QFN32_5X5_LONGLEADS
Z1, Z2, Z3: PGB1010603; SPARKFUN-RESISTORS_0603-RES; MPN PGB1010603NRHF

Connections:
+5V: C4.1, U1.6 (VREGIN); also elsewhere on the board
ARM_3V3: C1.1, C2.1, C3.1, C5.1, TP9.TP, U1.1 (VDD), U1.5 (VOUT33), U1.7 (VDDA), U1.11 (VBAT); also elsewhere on the board
ARM_BOOTLOADER: TP16.TP, U1.25 (PTC4)
ARM_RESET: TP14.TP, U1.19 (RESET_B)
ARM_RX: TP13.TP, U1.13 (PTA1); also elsewhere on the board
ARM_RX1: U1.24 (PTC3); also elsewhere on the board
ARM_TCK: TP11.TP, U1.12 (PTA0)
ARM_TMS: TP10.TP, U1.15 (PTA3)
ARM_TX: TP12.TP, U1.14 (PTA2); also elsewhere on the board
ESP_GPIO0: U1.21 (PTB1); also elsewhere on the board
ESP_RESET: U1.20 (PTB0); also elsewhere on the board
GND: C1.2, C2.2, C3.2, C4.2, C5.2, J1.PAD$1 (SHIELD), J1.PAD$2 (SHIELD), J1.PAD$3 (SHIELD), J1.PAD$4 (SHIELD), J1.PAD$5 (SHIELD), J1.PAD$6 (SHIELD), J1.PAD$7 (SHIELD), J1.PAD$8 (SHIELD), J1.PAD$9 (SHIELD), J1.PAD$10 (SHIELD), J1.PIN$5 (GND), Q1.P$2, Q1.P$4, TP18.TP, U1.2 (VSS), U1.8 (VSSA), U1.PAD@1 (VSS), U1.PAD@4 (VSS), U1.PAD@9 (VSS), U1.PAD@11 (VSS), Z1.1, Z2.1, Z3.1; also elsewhere on the board
LED_CLK: U1.26 (PTC5); also elsewhere on the board
LED_DAT_0: U1.27 (PTC6); also elsewhere on the board
LED_HS_EN: U1.22 (PTC1); also elsewhere on the board
LED_OE: U1.16 (PTA4); also elsewhere on the board
LED_ROW_A: U1.30 (PTD5); also elsewhere on the board
LED_ROW_B: U1.31 (PTD6); also elsewhere on the board
LED_ROW_C: U1.32 (PTD7); also elsewhere on the board
LED_STB: U1.29 (PTD4); also elsewhere on the board
unnamed: Q1.P$3 (2), U1.17 (PTA18)
unnamed: J1.PIN$2 (D-), R7.1, Z1.2
unnamed: J1.PIN$3 (D+), R8.1, Z2.2
unnamed: Q1.P$1 (1), U1.18 (PTA19)
USB_5V: J1.PIN$1 (VCC), Z3.2; also elsewhere on the board
USB_D+: R8.2, U1.3 (USB0_DP)
USB_D-: R7.2, U1.4 (USB0_DM)

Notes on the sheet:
Pin assignments for matrix output: LED_DAT + LED_CLK use ESPI hardware LED_OE and LED_STB need to be on pins with FTM0 capability LED_ROW_* are GPIO and need to be together on a unique port
Provides LED drive signal, USB/Serial conversion
ARM microcontroller
Place near 1,7,11
Place near 5
Place near 6
Battery charge, ARM programming using DFU, ESP programming using ACM
USB port
Pin assignments for USB/Serial conversion: ARM_RX and ARM_TX are UART0 ESP_RESET is virtually connected to RTS ESP_GPIO0 is virtually connected to DTR
If shorted during boot, the ARM will go directly into DFU mode. Useful if the application firmware becomes unstable. Note that this is a software feature- it is implemented by the bootloader firmware.
ARM boot select
Used for automated production testing
JTAG interface for ARM

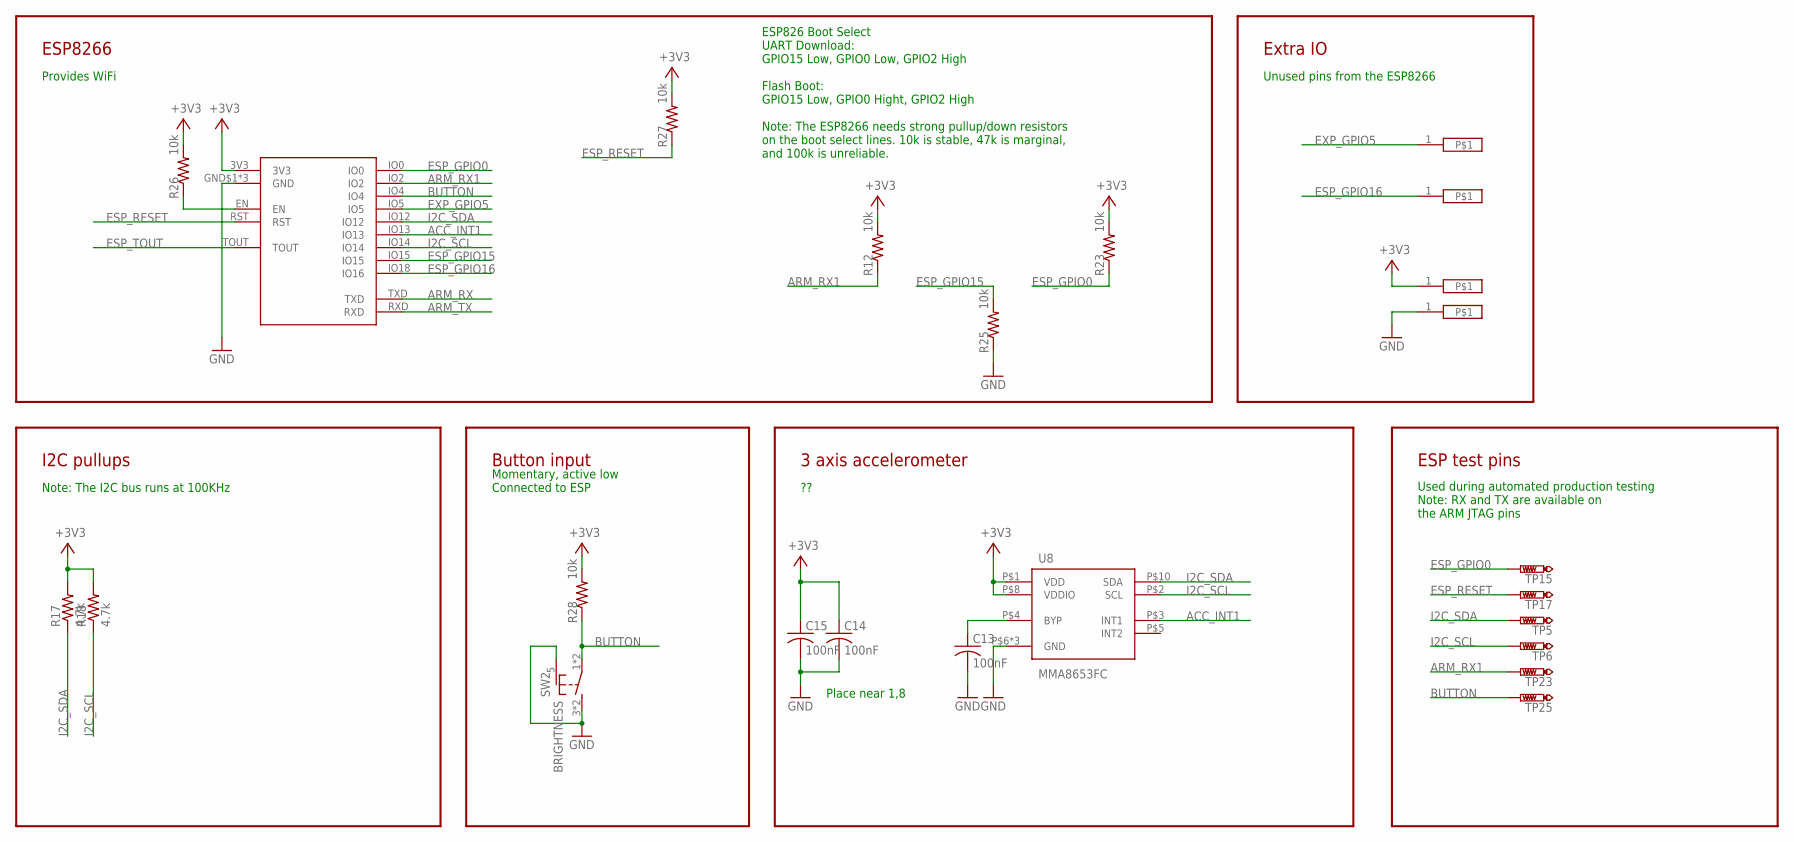
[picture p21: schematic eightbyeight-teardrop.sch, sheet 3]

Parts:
C13, C14, C15: 100nF; CAP_0402
R12, R23, R25, R26, R27, R28: 10k; R_0402
R17, R18: 4.7k; R_0402
SW2: BRIGHTNESS; TD-07XB
TP5, TP6, TP15, TP17, TP23, TP25: PTR1B1,27; B1,27
U6: ESP_WROOM_02
U8: MMA8653FC; VFDFN-10
U$2, U$6, U$9, U$10: TEST_POINT; IO_HOLE_3MM

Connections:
+3V3: C14.1, C15.1, R12.2, R17.2, R18.2, R23.2, R26.2, R27.2, R28.2, U6.3V3, U8.P$1 (VDD), U8.P$8 (VDDIO), U$10.1; also elsewhere on the board
ACC_INT1: U6.IO13, U8.P$3 (INT1)
ARM_RX: U6.TXD; also elsewhere on the board
ARM_RX1: R12.1, TP23.TP, U6.IO2; also elsewhere on the board
ARM_TX: U6.RXD; also elsewhere on the board
BUTTON: R28.1, SW2.1, SW2.2, TP25.TP, U6.IO4
ESP_ENABLE: R26.1, U6.EN
ESP_GPIO0: R23.1, TP15.TP, U6.IO0; also elsewhere on the board
ESP_GPIO15: R25.2, U6.IO15
ESP_GPIO16: U6.IO18 (IO16), U$9.1
ESP_RESET: R27.1, TP17.TP, U6.RST; also elsewhere on the board
ESP_TOUT: U6.TOUT
EXP_GPIO5: U6.IO5, U$6.1
GND: C13.2, C14.2, C15.2, R25.1, SW2.3 (S), SW2.4 (S), SW2.5 (SHIELD), U6.GND$1 (GND), U6.GND$2 (GND), U6.GND$3 (GND), U8.P$6 (GND), U8.P$7 (GND), U8.P$9 (GND), U$2.1; also elsewhere on the board
I2C_SCL: R18.1, TP6.TP, U6.IO14, U8.P$2 (SCL)
I2C_SDA: R17.1, TP5.TP, U6.IO12, U8.P$10 (SDA)
unnamed: C13.1, U8.P$4 (BYP)

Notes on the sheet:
Provides WiFi
ESP8266
ESP826 Boot Select UART Download: GPIO15 Low, GPIO0 Low, GPIO2 High Flash Boot: GPIO15 Low, GPIO0 Hight, GPIO2 High Note: The ESP8266 needs strong pullup/down resistors on the boot select lines. 10k is stable, 47k is marginal, and 100k is unreliable.
Note: The I2C bus runs at 100KHz
I2C pullups
Momentary, active low Connected to ESP
Button input
3 axis accelerometer
Place near 1,8
Unused pins from the ESP8266
Extra IO
Used during automated production testing Note: RX and TX are available on the ARM JTAG pins
ESP test pins

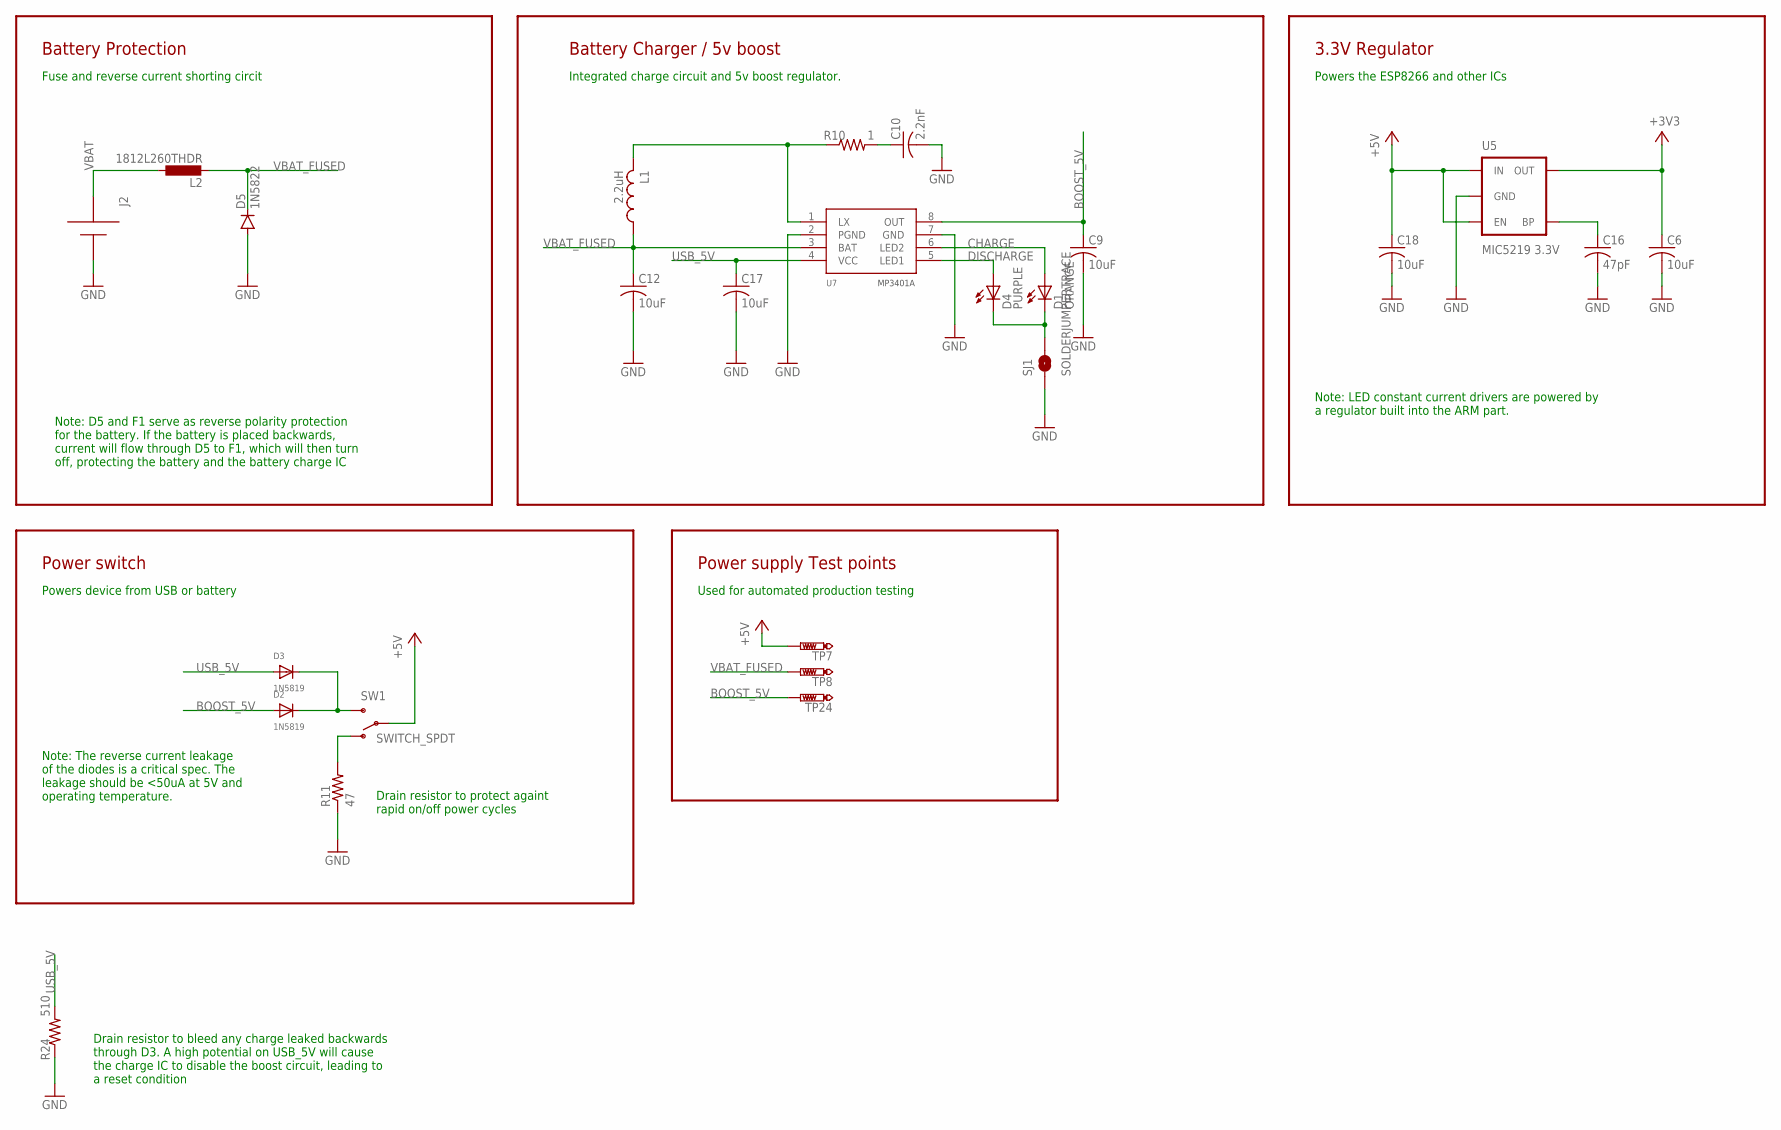
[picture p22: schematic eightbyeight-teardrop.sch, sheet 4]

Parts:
C6, C9, C12, C17, C18: 10uF; CAP_0805
C10: 2.2nF; CAP_0603
C16: 47pF; CAP_0402
D1: ORANGE; CHIP-LED0603
D2, D3: 1N5819; SOD-123
D4: PURPLE; CHIP-LED0603
D5: 1N5822; SMA-DIODE
J2: BATTERYAA_SMD; BATTERY_AA_SMD
L1: 2.2uH; INDUCTOR_CD43
L2: 1812L260THDR; L1812
R10: 1; R_0603
R11: 47; R_0805
R24: 510; R_0603
SJ1: SOLDERJUMPERTRACE; SJ_2S-TRACE
SW1: SWITCH_SPDT; SWITCH_6P-2POS
TP7, TP8, TP24: PTR1B1,27; B1,27
U5: MIC5219 3.3V; SOT23-5
U7: MP3401A; SO08-150

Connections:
+3V3: C6.1, U5.5 (OUT); also elsewhere on the board
+5V: C18.1, SW1.P0, SW1.P1, TP7.TP, U5.1 (IN), U5.3 (EN); also elsewhere on the board
+5V_BLEED: R11.2, SW1.O0 (O), SW1.O1 (O)
+5V_SWITCH: D2.C, D3.C, SW1.S0 (S), SW1.S1 (S)
BOOST_5V: C9.1, D2.A, TP24.TP, U7.8 (OUT)
CHARGE: D1.A, U7.6 (LED2)
DISCHARGE: D4.A, U7.5 (LED1)
GND: C6.2, C9.2, C10.2, C12.2, C16.2, C17.2, C18.2, D5.A, J2.-, R11.1, R24.1, SJ1.1, U5.2 (GND), U7.2 (PGND), U7.7 (GND); also elsewhere on the board
unnamed: D1.C, D4.C, SJ1.2
unnamed: L1.P$2 (2), R10.1, U7.1 (LX)
unnamed: C10.1, R10.2
unnamed: C16.1, U5.4 (BP)
USB_5V: C17.1, D3.A, R24.2, U7.4 (VCC); also elsewhere on the board
VBAT: J2.+, L2.1
VBAT_FUSED: C12.1, D5.C, L1.P$1 (1), L2.2, TP8.TP, U7.3 (BAT)

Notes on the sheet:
Fuse and reverse current shorting circit
Battery Protection
Powers the ESP8266 and other ICs
3.3V Regulator
Note: LED constant current drivers are powered by a regulator built into the ARM part.
Drain resistor to protect againt rapid on/off power cycles
Powers device from USB or battery
Power switch
Used for automated production testing
Power supply Test points
Note: D5 and F1 serve as reverse polarity protection for the battery. If the battery is placed backwards, current will flow through D5 to F1, which will then turn off, protecting the battery and the battery charge IC
Integrated charge circuit and 5v boost regulator.
Battery Charger / 5v boost
Drain resistor to bleed any charge leaked backwards through D3. A high potential on USB_5V will cause the charge IC to disable the boost circuit, leading to a reset condition
Note: The reverse current leakage of the diodes is a critical spec. The leakage should be <50uA at 5V and operating temperature.

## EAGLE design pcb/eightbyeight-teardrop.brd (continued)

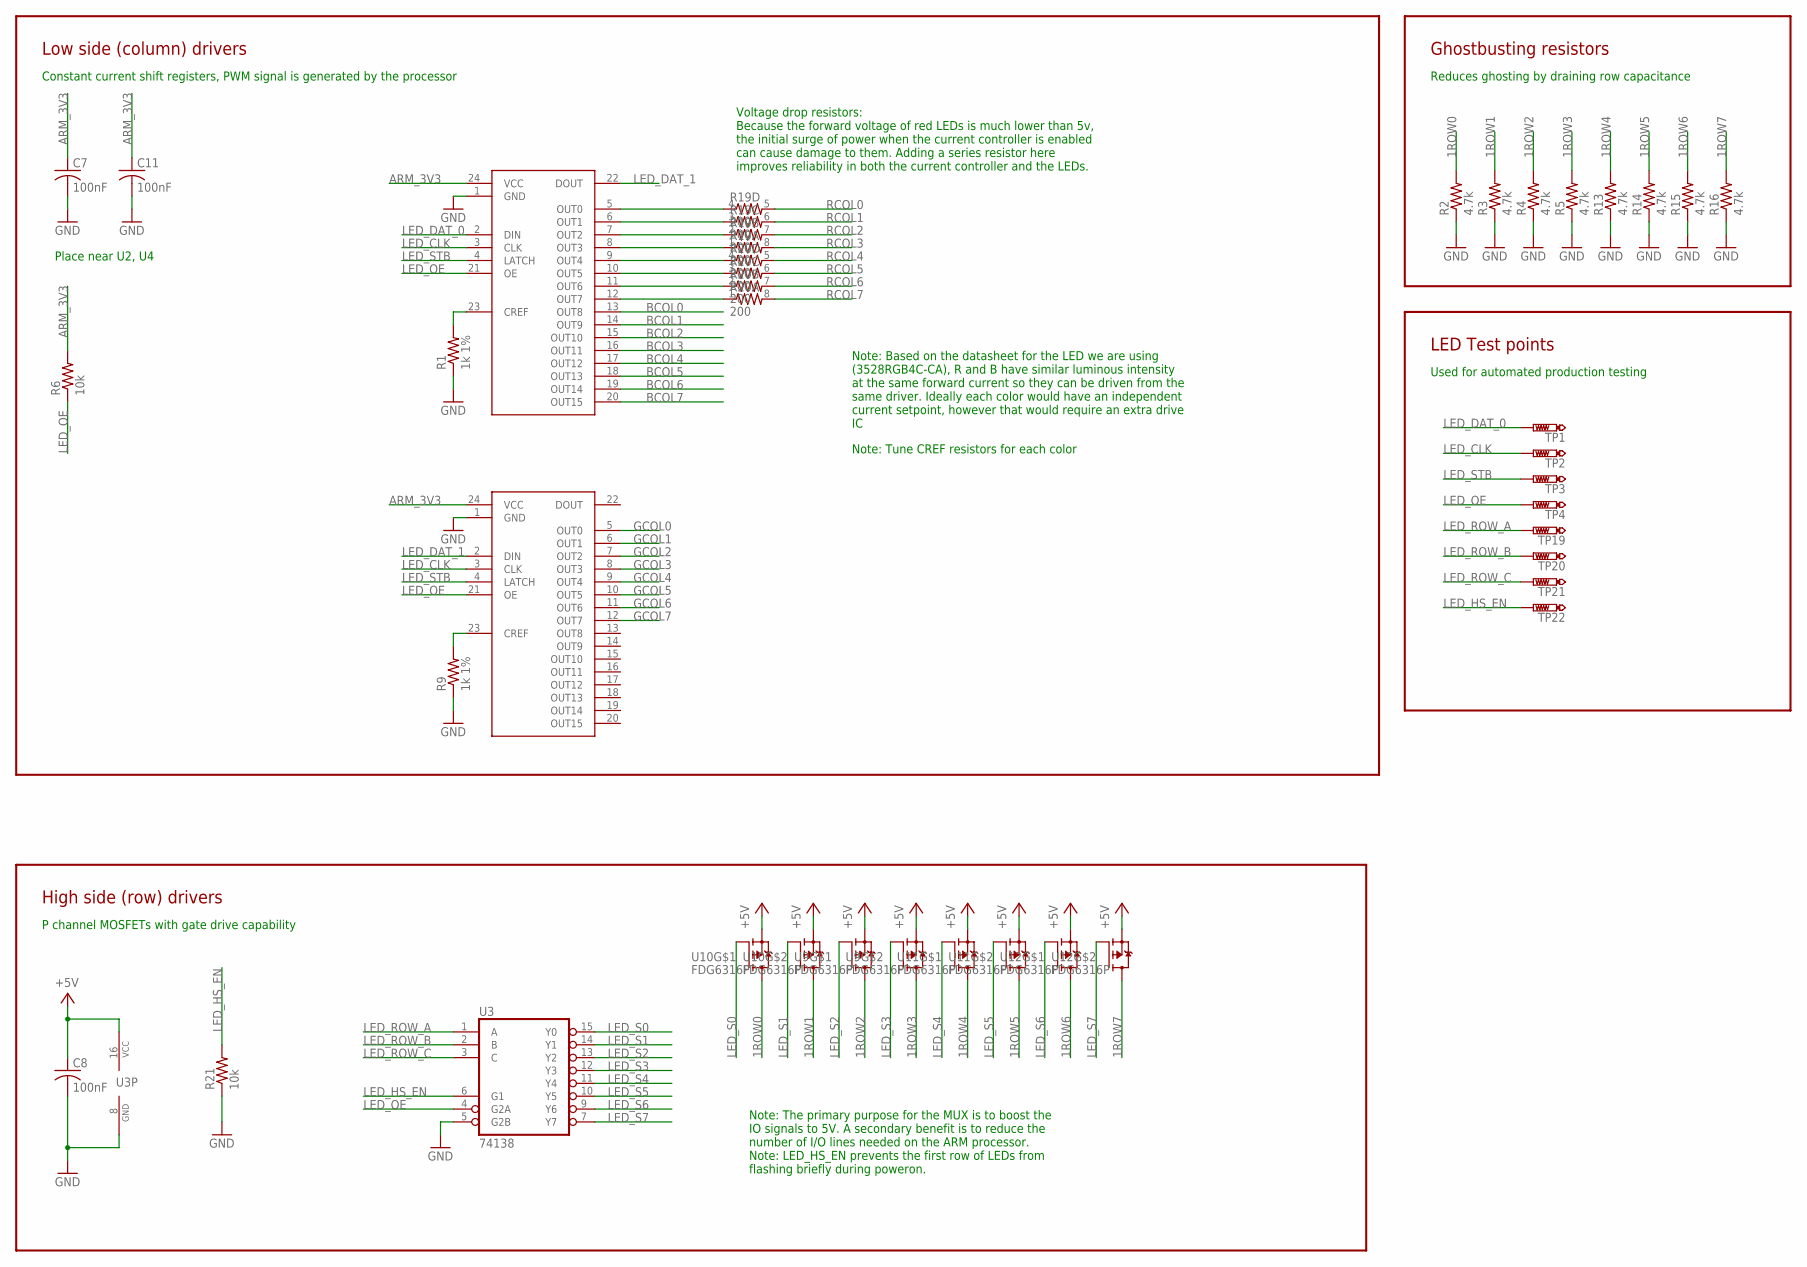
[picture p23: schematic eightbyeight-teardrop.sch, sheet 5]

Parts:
C7, C8, C11: 100nF; CAP_0402
R1, R9: 1k 1%; R_0402
R2, R3, R4, R5, R13, R14, R15, R16: 4.7k; R_0402
R6, R21: 10k; R_0402
R19, R20: 200; 0603-ARV
TP1, TP2, TP3, TP4, TP19, TP20, TP21, TP22: PTR1B1,27; B1,27
U2, U4: ICN2026; SSOP24-150
U3: 74138; TSSOP16
U9, U10, U11, U12: FDG6316P; SC70-6L

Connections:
1ROW0: R2.2, U10.6 (D); also elsewhere on the board
1ROW1: R3.2, U10.3 (D); also elsewhere on the board
1ROW2: R4.2, U9.6 (D); also elsewhere on the board
1ROW3: R5.2, U9.3 (D); also elsewhere on the board
1ROW4: R13.2, U11.6 (D); also elsewhere on the board
1ROW5: R14.2, U11.3 (D); also elsewhere on the board
1ROW6: R15.2, U12.6 (D); also elsewhere on the board
1ROW7: R16.2, U12.3 (D); also elsewhere on the board
+5V: C8.1, U3.16 (VCC), U9.1 (S), U9.4 (S), U10.1 (S), U10.4 (S), U11.1 (S), U11.4 (S), U12.1 (S), U12.4 (S); also elsewhere on the board
ARM_3V3: C7.1, C11.1, R6.2, U2.24 (VCC), U4.24 (VCC); also elsewhere on the board
BCOL0: U2.13 (OUT8); also elsewhere on the board
BCOL1: U2.14 (OUT9); also elsewhere on the board
BCOL2: U2.15 (OUT10); also elsewhere on the board
BCOL3: U2.16 (OUT11); also elsewhere on the board
BCOL4: U2.17 (OUT12); also elsewhere on the board
BCOL5: U2.18 (OUT13); also elsewhere on the board
BCOL6: U2.19 (OUT14); also elsewhere on the board
BCOL7: U2.20 (OUT15); also elsewhere on the board
GCOL0: U4.5 (OUT0); also elsewhere on the board
GCOL1: U4.6 (OUT1); also elsewhere on the board
GCOL2: U4.7 (OUT2); also elsewhere on the board
GCOL3: U4.8 (OUT3); also elsewhere on the board
GCOL4: U4.9 (OUT4); also elsewhere on the board
GCOL5: U4.10 (OUT5); also elsewhere on the board
GCOL6: U4.11 (OUT6); also elsewhere on the board
GCOL7: U4.12 (OUT7); also elsewhere on the board
GND: C7.2, C8.2, C11.2, R1.1, R2.1, R3.1, R4.1, R5.1, R9.1, R13.1, R14.1, R15.1, R16.1, R21.1, U2.1 (GND), U3.5 (G2B), U3.8 (GND), U4.1 (GND); also elsewhere on the board
LED_CLK: TP2.TP, U2.3 (CLK), U4.3 (CLK); also elsewhere on the board
LED_DAT_0: TP1.TP, U2.2 (DIN); also elsewhere on the board
LED_DAT_1: U2.22 (DOUT), U4.2 (DIN)
LED_HS_EN: R21.2, TP22.TP, U3.6 (G1); also elsewhere on the board
LED_OE: R6.1, TP4.TP, U2.21 (OE), U3.4 (G2A), U4.21 (OE); also elsewhere on the board
LED_ROW_A: TP19.TP, U3.1 (A); also elsewhere on the board
LED_ROW_B: TP20.TP, U3.2 (B); also elsewhere on the board
LED_ROW_C: TP21.TP, U3.3 (C); also elsewhere on the board
LED_S0: U3.15 (Y0), U10.2 (G)
LED_S1: U3.14 (Y1), U10.5 (G)
LED_S2: U3.13 (Y2), U9.2 (G)
LED_S3: U3.12 (Y3), U9.5 (G)
LED_S4: U3.11 (Y4), U11.2 (G)
LED_S5: U3.10 (Y5), U11.5 (G)
LED_S6: U3.9 (Y6), U12.2 (G)
LED_S7: U3.7 (Y7), U12.5 (G)
LED_STB: TP3.TP, U2.4 (LATCH), U4.4 (LATCH); also elsewhere on the board
unnamed: R9.2, U4.23 (CREF)
unnamed: R1.2, U2.23 (CREF)
RCOL0: R19.5 (2); also elsewhere on the board
RCOL0_: R19.4 (1), U2.5 (OUT0)
RCOL1: R19.6 (2); also elsewhere on the board
RCOL1_: R19.3 (1), U2.6 (OUT1)
RCOL2: R19.7 (2); also elsewhere on the board
RCOL2_: R19.2 (1), U2.7 (OUT2)
RCOL3: R19.8 (2); also elsewhere on the board
RCOL3_: R19.1, U2.8 (OUT3)
RCOL4: R20.5 (2); also elsewhere on the board
RCOL4_: R20.4 (1), U2.9 (OUT4)
RCOL5: R20.6 (2); also elsewhere on the board
RCOL5_: R20.3 (1), U2.10 (OUT5)
RCOL6: R20.7 (2); also elsewhere on the board
RCOL6_: R20.2 (1), U2.11 (OUT6)
RCOL7: R20.8 (2); also elsewhere on the board
RCOL7_: R20.1, U2.12 (OUT7)

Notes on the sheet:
Constant current shift registers, PWM signal is generated by the processor
Low side (column) drivers
Note: Tune CREF resistors for each color
Place near U2, U4
P channel MOSFETs with gate drive capability
High side (row) drivers
Reduces ghosting by draining row capacitance
Ghostbusting resistors
Voltage drop resistors: Because the forward voltage of red LEDs is much lower than 5v, the initial surge of power when the current controller is enabled can cause damage to them. Adding a series resistor here improves reliability in both the current controller and the LEDs.
Note: Based on the datasheet for the LED we are using (3528RGB4C-CA), R and B have similar luminous intensity at the same forward current so they can be driven from the same driver. Ideally each color would have an independent current setpoint, however that would require an extra drive IC
Note: The primary purpose for the MUX is to boost the IO signals to 5V. A secondary benefit is to reduce the number of I/O lines needed on the ARM processor. Note: LED_HS_EN prevents the first row of LEDs from flashing briefly during poweron.
Used for automated production testing
LED Test points

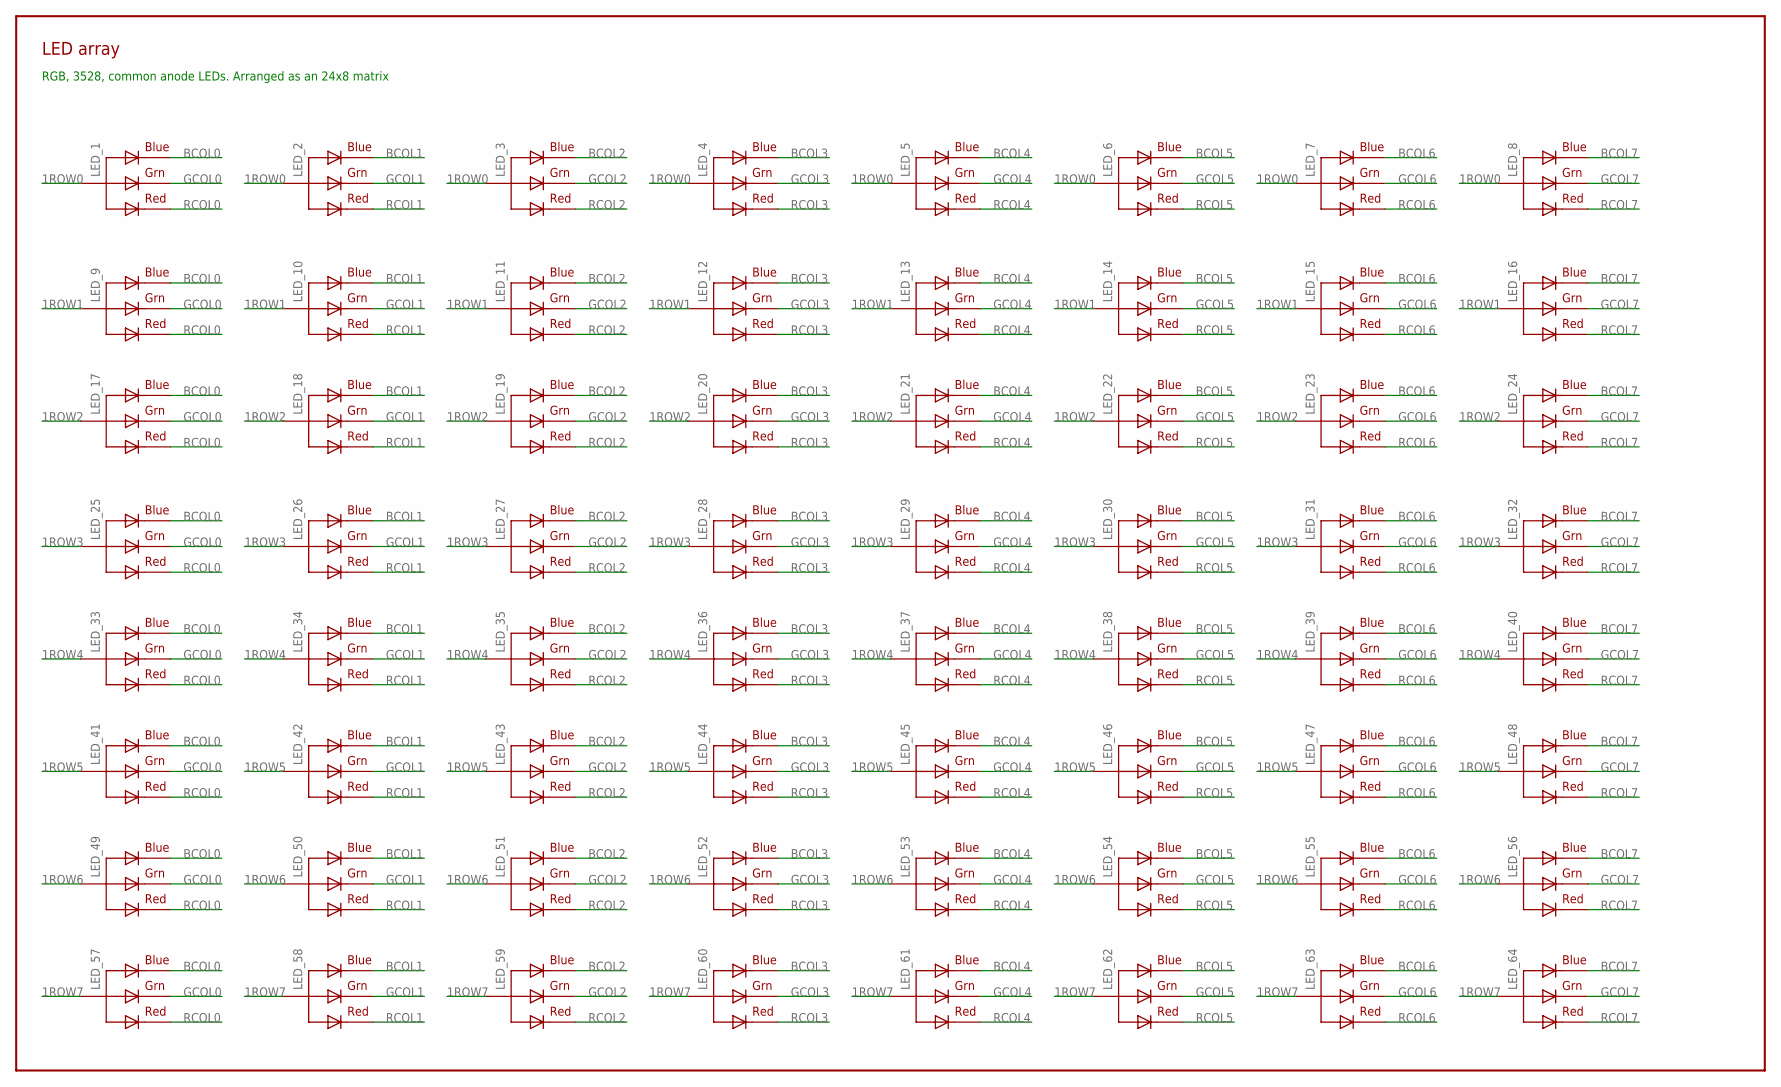
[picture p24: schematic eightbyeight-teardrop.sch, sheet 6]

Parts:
LED_1, LED_2, LED_3, LED_4, LED_5, LED_6, LED_7, LED_8, LED_9, LED_10, LED_11, LED_12, LED_13, LED_14, LED_15, LED_16, LED_17, LED_18, LED_19, LED_20, LED_21, LED_22, LED_23, LED_24, LED_25, LED_26, LED_27, LED_28, LED_29, LED_30, LED_31, LED_32, LED_33, LED_34, LED_35, LED_36, LED_37, LED_38, LED_39, LED_40, LED_41, LED_42, LED_43, LED_44, LED_45, LED_46, LED_47, LED_48, LED_49, LED_50, LED_51, LED_52, LED_53, LED_54, LED_55, LED_56, LED_57, LED_58, LED_59, LED_60, LED_61, LED_62, LED_63, LED_64: LED_RGB_CA3528; LED_3528

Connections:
1ROW0: LED_1.2 (VCC), LED_2.2 (VCC), LED_3.2 (VCC), LED_4.2 (VCC), LED_5.2 (VCC), LED_6.2 (VCC), LED_7.2 (VCC), LED_8.2 (VCC); also elsewhere on the board
1ROW1: LED_9.2 (VCC), LED_10.2 (VCC), LED_11.2 (VCC), LED_12.2 (VCC), LED_13.2 (VCC), LED_14.2 (VCC), LED_15.2 (VCC), LED_16.2 (VCC); also elsewhere on the board
1ROW2: LED_17.2 (VCC), LED_18.2 (VCC), LED_19.2 (VCC), LED_20.2 (VCC), LED_21.2 (VCC), LED_22.2 (VCC), LED_23.2 (VCC), LED_24.2 (VCC); also elsewhere on the board
1ROW3: LED_25.2 (VCC), LED_26.2 (VCC), LED_27.2 (VCC), LED_28.2 (VCC), LED_29.2 (VCC), LED_30.2 (VCC), LED_31.2 (VCC), LED_32.2 (VCC); also elsewhere on the board
1ROW4: LED_33.2 (VCC), LED_34.2 (VCC), LED_35.2 (VCC), LED_36.2 (VCC), LED_37.2 (VCC), LED_38.2 (VCC), LED_39.2 (VCC), LED_40.2 (VCC); also elsewhere on the board
1ROW5: LED_41.2 (VCC), LED_42.2 (VCC), LED_43.2 (VCC), LED_44.2 (VCC), LED_45.2 (VCC), LED_46.2 (VCC), LED_47.2 (VCC), LED_48.2 (VCC); also elsewhere on the board
1ROW6: LED_49.2 (VCC), LED_50.2 (VCC), LED_51.2 (VCC), LED_52.2 (VCC), LED_53.2 (VCC), LED_54.2 (VCC), LED_55.2 (VCC), LED_56.2 (VCC); also elsewhere on the board
1ROW7: LED_57.2 (VCC), LED_58.2 (VCC), LED_59.2 (VCC), LED_60.2 (VCC), LED_61.2 (VCC), LED_62.2 (VCC), LED_63.2 (VCC), LED_64.2 (VCC); also elsewhere on the board
BCOL0: LED_1.3 (BLUE), LED_9.3 (BLUE), LED_17.3 (BLUE), LED_25.3 (BLUE), LED_33.3 (BLUE), LED_41.3 (BLUE), LED_49.3 (BLUE), LED_57.3 (BLUE); also elsewhere on the board
BCOL1: LED_2.3 (BLUE), LED_10.3 (BLUE), LED_18.3 (BLUE), LED_26.3 (BLUE), LED_34.3 (BLUE), LED_42.3 (BLUE), LED_50.3 (BLUE), LED_58.3 (BLUE); also elsewhere on the board
BCOL2: LED_3.3 (BLUE), LED_11.3 (BLUE), LED_19.3 (BLUE), LED_27.3 (BLUE), LED_35.3 (BLUE), LED_43.3 (BLUE), LED_51.3 (BLUE), LED_59.3 (BLUE); also elsewhere on the board
BCOL3: LED_4.3 (BLUE), LED_12.3 (BLUE), LED_20.3 (BLUE), LED_28.3 (BLUE), LED_36.3 (BLUE), LED_44.3 (BLUE), LED_52.3 (BLUE), LED_60.3 (BLUE); also elsewhere on the board
BCOL4: LED_5.3 (BLUE), LED_13.3 (BLUE), LED_21.3 (BLUE), LED_29.3 (BLUE), LED_37.3 (BLUE), LED_45.3 (BLUE), LED_53.3 (BLUE), LED_61.3 (BLUE); also elsewhere on the board
BCOL5: LED_6.3 (BLUE), LED_14.3 (BLUE), LED_22.3 (BLUE), LED_30.3 (BLUE), LED_38.3 (BLUE), LED_46.3 (BLUE), LED_54.3 (BLUE), LED_62.3 (BLUE); also elsewhere on the board
BCOL6: LED_7.3 (BLUE), LED_15.3 (BLUE), LED_23.3 (BLUE), LED_31.3 (BLUE), LED_39.3 (BLUE), LED_47.3 (BLUE), LED_55.3 (BLUE), LED_63.3 (BLUE); also elsewhere on the board
BCOL7: LED_8.3 (BLUE), LED_16.3 (BLUE), LED_24.3 (BLUE), LED_32.3 (BLUE), LED_40.3 (BLUE), LED_48.3 (BLUE), LED_56.3 (BLUE), LED_64.3 (BLUE); also elsewhere on the board
GCOL0: LED_1.4 (GREEN), LED_9.4 (GREEN), LED_17.4 (GREEN), LED_25.4 (GREEN), LED_33.4 (GREEN), LED_41.4 (GREEN), LED_49.4 (GREEN), LED_57.4 (GREEN); also elsewhere on the board
GCOL1: LED_2.4 (GREEN), LED_10.4 (GREEN), LED_18.4 (GREEN), LED_26.4 (GREEN), LED_34.4 (GREEN), LED_42.4 (GREEN), LED_50.4 (GREEN), LED_58.4 (GREEN); also elsewhere on the board
GCOL2: LED_3.4 (GREEN), LED_11.4 (GREEN), LED_19.4 (GREEN), LED_27.4 (GREEN), LED_35.4 (GREEN), LED_43.4 (GREEN), LED_51.4 (GREEN), LED_59.4 (GREEN); also elsewhere on the board
GCOL3: LED_4.4 (GREEN), LED_12.4 (GREEN), LED_20.4 (GREEN), LED_28.4 (GREEN), LED_36.4 (GREEN), LED_44.4 (GREEN), LED_52.4 (GREEN), LED_60.4 (GREEN); also elsewhere on the board
GCOL4: LED_5.4 (GREEN), LED_13.4 (GREEN), LED_21.4 (GREEN), LED_29.4 (GREEN), LED_37.4 (GREEN), LED_45.4 (GREEN), LED_53.4 (GREEN), LED_61.4 (GREEN); also elsewhere on the board
GCOL5: LED_6.4 (GREEN), LED_14.4 (GREEN), LED_22.4 (GREEN), LED_30.4 (GREEN), LED_38.4 (GREEN), LED_46.4 (GREEN), LED_54.4 (GREEN), LED_62.4 (GREEN); also elsewhere on the board
GCOL6: LED_7.4 (GREEN), LED_15.4 (GREEN), LED_23.4 (GREEN), LED_31.4 (GREEN), LED_39.4 (GREEN), LED_47.4 (GREEN), LED_55.4 (GREEN), LED_63.4 (GREEN); also elsewhere on the board
GCOL7: LED_8.4 (GREEN), LED_16.4 (GREEN), LED_24.4 (GREEN), LED_32.4 (GREEN), LED_40.4 (GREEN), LED_48.4 (GREEN), LED_56.4 (GREEN), LED_64.4 (GREEN); also elsewhere on the board
RCOL0: LED_1.1 (RED), LED_9.1 (RED), LED_17.1 (RED), LED_25.1 (RED), LED_33.1 (RED), LED_41.1 (RED), LED_49.1 (RED), LED_57.1 (RED); also elsewhere on the board
RCOL1: LED_2.1 (RED), LED_10.1 (RED), LED_18.1 (RED), LED_26.1 (RED), LED_34.1 (RED), LED_42.1 (RED), LED_50.1 (RED), LED_58.1 (RED); also elsewhere on the board
RCOL2: LED_3.1 (RED), LED_11.1 (RED), LED_19.1 (RED), LED_27.1 (RED), LED_35.1 (RED), LED_43.1 (RED), LED_51.1 (RED), LED_59.1 (RED); also elsewhere on the board
RCOL3: LED_4.1 (RED), LED_12.1 (RED), LED_20.1 (RED), LED_28.1 (RED), LED_36.1 (RED), LED_44.1 (RED), LED_52.1 (RED), LED_60.1 (RED); also elsewhere on the board
RCOL4: LED_5.1 (RED), LED_13.1 (RED), LED_21.1 (RED), LED_29.1 (RED), LED_37.1 (RED), LED_45.1 (RED), LED_53.1 (RED), LED_61.1 (RED); also elsewhere on the board
RCOL5: LED_6.1 (RED), LED_14.1 (RED), LED_22.1 (RED), LED_30.1 (RED), LED_38.1 (RED), LED_46.1 (RED), LED_54.1 (RED), LED_62.1 (RED); also elsewhere on the board
RCOL6: LED_7.1 (RED), LED_15.1 (RED), LED_23.1 (RED), LED_31.1 (RED), LED_39.1 (RED), LED_47.1 (RED), LED_55.1 (RED), LED_63.1 (RED); also elsewhere on the board
RCOL7: LED_8.1 (RED), LED_16.1 (RED), LED_24.1 (RED), LED_32.1 (RED), LED_40.1 (RED), LED_48.1 (RED), LED_56.1 (RED), LED_64.1 (RED); also elsewhere on the board

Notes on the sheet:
RGB, 3528, common anode LEDs. Arranged as an 24x8 matrix
LED array

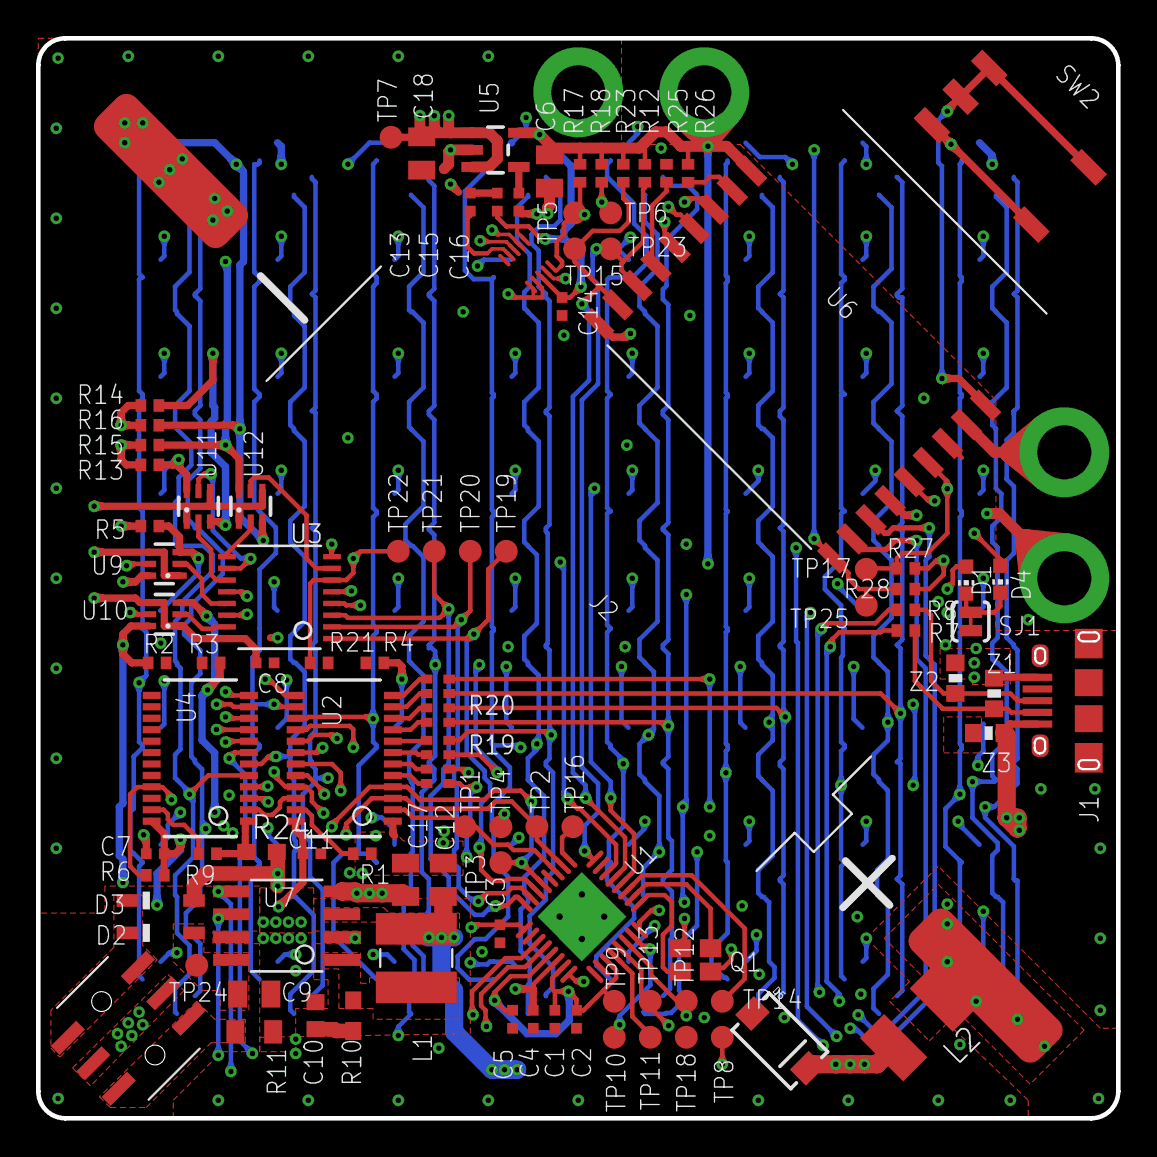
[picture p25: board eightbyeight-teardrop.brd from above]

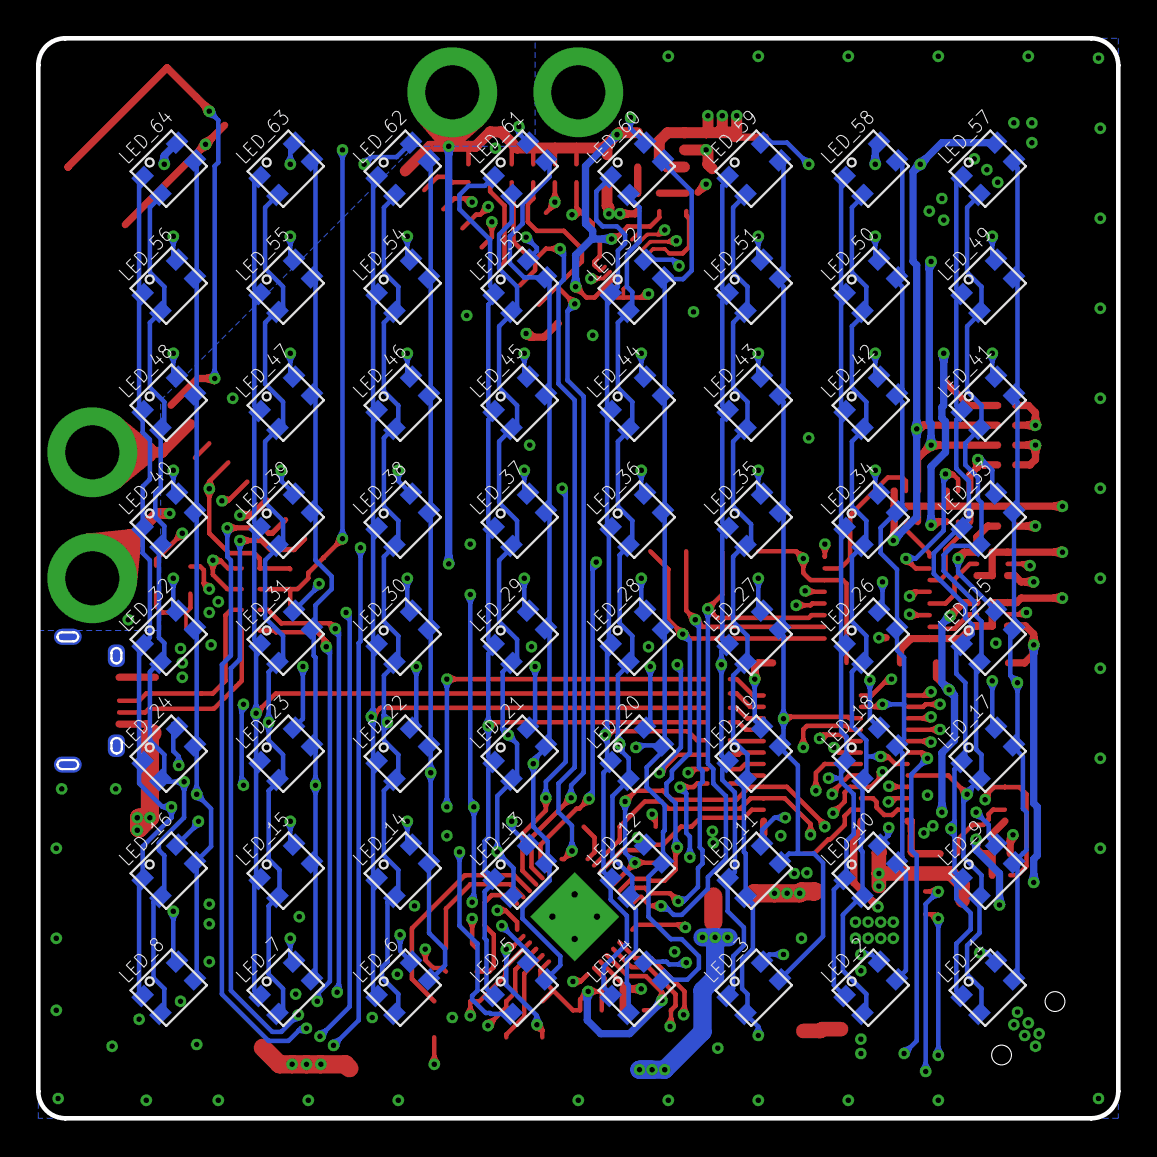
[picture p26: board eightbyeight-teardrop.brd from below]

Board: 4 copper layers, 60.0 x 60.0 mm, 166 parts (64 on the bottom side), 99 nets.

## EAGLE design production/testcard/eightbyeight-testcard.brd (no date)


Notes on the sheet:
Revision Notes/Changelog Revision A: -Matches Rev D/E/F application versions -On JTAG, ARM_TX and ARM_RX are swapped -LED_DAT_0 not connected to digital header Revision B: -Put connectors and labels on proper side -Make test card longer to give space for ribbon cables TODO: -Swap ARM_TX and ARM_RX 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
EightByEight Test card
Copyright 2016 Blinkinlabs, LLC


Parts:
5V: TEST_POINT1.4MM; IO_HOLE_1.4MM
+3V3: TEST_POINT2.55MM; IO_HOLE_2.55MM
ANALOG_TEST: M08X2; 2X8
ARM_3V3: TEST_POINT1.4MM; IO_HOLE_1.4MM
ARM_BOOT: TEST_POINT1.4MM; IO_HOLE_1.4MM
ARM_RESET: TEST_POINT1.4MM; IO_HOLE_1.4MM
ARM_RX, ARM_RX1: TEST_POINT1.4MM; IO_HOLE_1.4MM
ARM_TCK: TEST_POINT1.4MM; IO_HOLE_1.4MM
ARM_TMS: TEST_POINT1.4MM; IO_HOLE_1.4MM
ARM_TX: TEST_POINT1.4MM; IO_HOLE_1.4MM
BOOST_5V: TEST_POINT1.4MM; IO_HOLE_1.4MM
BUTTON: TEST_POINT1.4MM; IO_HOLE_1.4MM
DIGITAL_TEST: M08X2; 2X8
ESP_GPIO0: TEST_POINT1.4MM; IO_HOLE_1.4MM
ESP_GPIO5, ESP_GPIO16: TEST_POINT2.55MM; IO_HOLE_2.55MM
ESP_RESET: TEST_POINT1.4MM; IO_HOLE_1.4MM
GND: TEST_POINT2.55MM; IO_HOLE_2.55MM
GND_: TEST_POINT1.4MM; IO_HOLE_1.4MM
I2C_SCL, I2C_SDA: TEST_POINT1.4MM; IO_HOLE_1.4MM
JTAG: JTAG_ARM_10PIN; 2X05-1.27MM-SMD
LED_CLK: TEST_POINT1.4MM; IO_HOLE_1.4MM
LED_DATA: TEST_POINT1.4MM; IO_HOLE_1.4MM
LED_OE: TEST_POINT1.4MM; IO_HOLE_1.4MM
LED_STB: TEST_POINT1.4MM; IO_HOLE_1.4MM
VBAT: TEST_POINT1.4MM; IO_HOLE_1.4MM

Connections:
+3V3: +3V3.P$1, ANALOG_TEST.7
+5V: 5V.P$1, ANALOG_TEST.5
ARM_3V3: ANALOG_TEST.9, ARM_3V3.P$1, JTAG.P$1 (VCC)
ARM_BOOTLOADER: ARM_BOOT.P$1, DIGITAL_TEST.1
ARM_RESET: ARM_RESET.P$1, JTAG.P$10 (RESET)
ARM_RX: ARM_RX.P$1, JTAG.P$8 (TDI)
ARM_RX1: ARM_RX1.P$1, DIGITAL_TEST.3
ARM_TCK: ARM_TCK.P$1, JTAG.P$4 (TCK)
ARM_TMS: ARM_TMS.P$1, JTAG.P$2 (TMS)
ARM_TX: ARM_TX.P$1, JTAG.P$6 (TDO)
BOOST_5V: ANALOG_TEST.1, BOOST_5V.P$1
BUTTON: BUTTON.P$1, DIGITAL_TEST.10
ESP_GPIO0: DIGITAL_TEST.2, ESP_GPIO0.P$1
ESP_GPIO5: DIGITAL_TEST.12, ESP_GPIO5.P$1
ESP_GPIO16: DIGITAL_TEST.5, ESP_GPIO16.P$1
ESP_RESET: DIGITAL_TEST.4, ESP_RESET.P$1
GND: ANALOG_TEST.2, ANALOG_TEST.4, ANALOG_TEST.6, ANALOG_TEST.8, ANALOG_TEST.10, ANALOG_TEST.12, ANALOG_TEST.14, ANALOG_TEST.16, DIGITAL_TEST.16, GND.P$1, GND_.P$1, JTAG.P$3 (GND), JTAG.P$5 (GND), JTAG.P$9 (GND)
I2C_SCL: DIGITAL_TEST.8, I2C_SCL.P$1
I2C_SDA: DIGITAL_TEST.6, I2C_SDA.P$1
LED_CLK: DIGITAL_TEST.9, LED_CLK.P$1
LED_DAT_0: DIGITAL_TEST.7, LED_DATA.P$1
LED_OE: DIGITAL_TEST.13, LED_OE.P$1
LED_STB: DIGITAL_TEST.11, LED_STB.P$1
VBAT: ANALOG_TEST.3, VBAT.P$1

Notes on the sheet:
If shorted during boot, the ARM will go directly into DFU mode. Useful if the application firmware becomes unstable. Note that this is a software feature- it is implemented by the bootloader firmware.
ARM boot select
Used for automated production testing
JTAG interface for ARM
Unused pins from the ESP8266
Extra IO
Used during automated production testing Note: RX and TX are available on the ARM JTAG pins
ESP test pins
Power supply Test points
LED Test points
Note: TX, RX pins have conflicts


Board: 2 copper layers, 70.0 x 60.0 mm, 28 parts (1 on the bottom side), 24 nets.

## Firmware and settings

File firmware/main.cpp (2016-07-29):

/*
 * EightByEight Blinky Badge
 *
 * Copyright (c) 2014, 2016 Blinkinlabs, LLC
 *
 * based on Fadecandy Firmware, Copyright (c) 2013 Micah Elizabeth Scott
 * 
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
 * THE SOFTWARE IS PROVIDED "AS IS", WITHOUT WARRANTY OF ANY KIND, EXPRESS OR
 * IMPLIED, INCLUDING BUT NOT LIMITED TO THE WARRANTIES OF MERCHANTABILITY, FITNESS
 * FOR A PARTICULAR PURPOSE AND NONINFRINGEMENT. IN NO EVENT SHALL THE AUTHORS OR
 * COPYRIGHT HOLDERS BE LIABLE FOR ANY CLAIM, DAMAGES OR OTHER LIABILITY, WHETHER
 * IN AN ACTION OF CONTRACT, TORT OR OTHERWISE, ARISING FROM, OUT OF OR IN
 * CONNECTION WITH THE SOFTWARE OR THE USE OR OTHER DEALINGS IN THE SOFTWARE.
 */

#include <math.h>
#include <stdlib.h>
#include <stdio.h>
#include "WProgram.h"
#include "usb_serial.h"
#include "usb_dev.h"

#include "eightbyeight.h"
#include "patterns.h"

#include "HardwareSerial.h"
#include "serialloop.h"
#include "usb_serial.h"

#include "matrix.h"

// Reserved RAM area for signalling entry to bootloader
extern uint32_t boot_token;

static void dfu_reboot()
{
    // Reboot to the Bootloader
    boot_token = 0x74624346;

    // Short delay to allow the host to receive the response to DFU_DETACH.
    uint32_t deadline = millis() + 10;
    while (millis() < deadline) {
        watchdog_refresh();
    }

    // Detach from USB, and use the watchdog to time out a 10ms USB disconnect.
    __disable_irq();
    USB0_CONTROL = 0;
    while (1);
}


void setupWatchdog() {
    // Change the watchdog timeout because the SPI access is too slow.
    const uint32_t watchdog_timeout = F_BUS / 2;  // 500ms

    WDOG_UNLOCK = WDOG_UNLOCK_SEQ1;
    WDOG_UNLOCK = WDOG_UNLOCK_SEQ2;
    asm volatile ("nop");
    asm volatile ("nop");
    WDOG_STCTRLH = WDOG_STCTRLH_ALLOWUPDATE | WDOG_STCTRLH_WDOGEN |
        WDOG_STCTRLH_WAITEN | WDOG_STCTRLH_STOPEN | WDOG_STCTRLH_CLKSRC;
    WDOG_PRESC = 0;
    WDOG_TOVALH = (watchdog_timeout >> 16) & 0xFFFF;
    WDOG_TOVALL = (watchdog_timeout)       & 0xFFFF;
}


extern "C" int main()
{
    setupWatchdog();

    initBoard();
    serialReset();

    // TODO: Make the baud rate adjustable
    serial_begin(BAUD2DIV(460800));
    serial_format(SERIAL_8N1);

    serial2_begin(BAUD2DIV(230400));
    serial2_format(SERIAL_8N1);

    matrix.setBrightness(1);
    matrix.begin();

    // Put the ESP8266 in reset mode
   // digitalWrite(ESP_RESET_PIN, LOW);
    background(0,255,255);

//    bool streamingMode = false;

    // Application main loop
    while (usb_dfu_state == DFU_appIDLE) {

        watchdog_refresh();
//        if(!streamingMode) {
//            colorSwirl();
//            matrix.show();
//        }

        // TODO: Something more robust
        #define MAX_SERIAL_TRANSFER 60
        char buff[MAX_SERIAL_TRANSFER];

        while(usb_serial_available()) {
            int bytesToTransfer = usb_serial_available();
            if(bytesToTransfer > MAX_SERIAL_TRANSFER) {
                bytesToTransfer = MAX_SERIAL_TRANSFER;
            }
            usb_serial_read(buff, bytesToTransfer);
            serial_write(buff, bytesToTransfer);
        }

        while(serial_available()) {

            int bytesToTransfer = serial_available();
            if(bytesToTransfer > MAX_SERIAL_TRANSFER) {
                bytesToTransfer = MAX_SERIAL_TRANSFER;
            }

            for(int byte = 0; byte < bytesToTransfer; byte++) {
                buff[byte] = serial_getchar();
            }
            usb_serial_write(buff, bytesToTransfer);
        }

        if(serial2_available()) {
//            streamingMode = true;
            serialLoop();
        }
    }

    // Reboot into DFU bootloader
    dfu_reboot();
}

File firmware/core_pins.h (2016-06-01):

/* Teensyduino Core Library
 * http://www.pjrc.com/teensy/
 * Copyright (c) 2013 PJRC.COM, LLC.
 *
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
 * 2. If the Software is incorporated into a build system that allows
 * selection among a list of target devices, then similar target
 * devices manufactured by PJRC.COM must be included in the list of
 * target devices and selectable in the same manner.
 *
 * THE SOFTWARE IS PROVIDED "AS IS", WITHOUT WARRANTY OF ANY KIND,
 * EXPRESS OR IMPLIED, INCLUDING BUT NOT LIMITED TO THE WARRANTIES OF
 * MERCHANTABILITY, FITNESS FOR A PARTICULAR PURPOSE AND
 * NONINFRINGEMENT. IN NO EVENT SHALL THE AUTHORS OR COPYRIGHT HOLDERS
 * BE LIABLE FOR ANY CLAIM, DAMAGES OR OTHER LIABILITY, WHETHER IN AN
 * ACTION OF CONTRACT, TORT OR OTHERWISE, ARISING FROM, OUT OF OR IN
 * CONNECTION WITH THE SOFTWARE OR THE USE OR OTHER DEALINGS IN THE
 * SOFTWARE.
 */

#ifndef _core_pins_h_
#define _core_pins_h_

#include "mk20dn64.h"
#include "pins_arduino.h"


#define HIGH		1
#define LOW		0
#define INPUT		0
#define OUTPUT		1
#define INPUT_PULLUP	2
#define LSBFIRST	0
#define MSBFIRST	1
#define _BV(n)		(1<<(n))
#define CHANGE		4
#define FALLING		2
#define RISING		3

// Pin				Arduino
//  0   PA0
//  1   PA1                     RXD
//  2   PA2                     TXD
//  3   PA3
//  4   PA4
//  5   PB0
//  6   PB1
//  7   PC1
//  8   PC2
//  9   PC3
// 10   PC4
// 11   PC5                     SCK
// 12   PC6                     MOSI
// 13   PC7                     MISO
// 14   PD4
// 15   PD5
// 16   PD6
// 17   PD7


// not available to user:
//	A18	CRYSTAL
//	A19	CRYSTAL

#define CORE_NUM_TOTAL_PINS     18
#define CORE_NUM_DIGITAL        18
#define CORE_NUM_INTERRUPT      18

#define CORE_PIN0_BIT		0
#define CORE_PIN1_BIT		1
#define CORE_PIN2_BIT		2
#define CORE_PIN3_BIT		3
#define CORE_PIN4_BIT		4
#define CORE_PIN5_BIT		0
#define CORE_PIN6_BIT		1
#define CORE_PIN7_BIT		1
#define CORE_PIN8_BIT		2
#define CORE_PIN9_BIT		3
#define CORE_PIN10_BIT		4
#define CORE_PIN11_BIT		5
#define CORE_PIN12_BIT		6
#define CORE_PIN13_BIT		7
#define CORE_PIN14_BIT		4
#define CORE_PIN15_BIT		5
#define CORE_PIN16_BIT		6
#define CORE_PIN17_BIT		7

#define CORE_PIN0_BITMASK	(1<<(CORE_PIN0_BIT))
#define CORE_PIN1_BITMASK	(1<<(CORE_PIN1_BIT))
#define CORE_PIN2_BITMASK	(1<<(CORE_PIN2_BIT))
#define CORE_PIN3_BITMASK	(1<<(CORE_PIN3_BIT))
#define CORE_PIN4_BITMASK	(1<<(CORE_PIN4_BIT))
#define CORE_PIN5_BITMASK	(1<<(CORE_PIN5_BIT))
#define CORE_PIN6_BITMASK	(1<<(CORE_PIN6_BIT))
#define CORE_PIN7_BITMASK	(1<<(CORE_PIN7_BIT))
#define CORE_PIN8_BITMASK	(1<<(CORE_PIN8_BIT))
#define CORE_PIN9_BITMASK	(1<<(CORE_PIN9_BIT))
#define CORE_PIN10_BITMASK	(1<<(CORE_PIN10_BIT))
#define CORE_PIN11_BITMASK	(1<<(CORE_PIN11_BIT))
#define CORE_PIN12_BITMASK	(1<<(CORE_PIN12_BIT))
#define CORE_PIN13_BITMASK	(1<<(CORE_PIN13_BIT))
#define CORE_PIN14_BITMASK	(1<<(CORE_PIN14_BIT))
#define CORE_PIN15_BITMASK	(1<<(CORE_PIN15_BIT))
#define CORE_PIN16_BITMASK	(1<<(CORE_PIN16_BIT))
#define CORE_PIN17_BITMASK	(1<<(CORE_PIN17_BIT))

#define CORE_PIN0_PORTREG	GPIOA_PDOR
#define CORE_PIN1_PORTREG	GPIOA_PDOR
#define CORE_PIN2_PORTREG	GPIOA_PDOR
#define CORE_PIN3_PORTREG	GPIOA_PDOR
#define CORE_PIN4_PORTREG	GPIOA_PDOR
#define CORE_PIN5_PORTREG	GPIOB_PDOR
#define CORE_PIN6_PORTREG	GPIOB_PDOR
#define CORE_PIN7_PORTREG	GPIOC_PDOR
#define CORE_PIN8_PORTREG	GPIOC_PDOR
#define CORE_PIN9_PORTREG	GPIOC_PDOR
#define CORE_PIN10_PORTREG	GPIOC_PDOR
#define CORE_PIN11_PORTREG	GPIOC_PDOR
#define CORE_PIN12_PORTREG	GPIOC_PDOR
#define CORE_PIN13_PORTREG	GPIOC_PDOR
#define CORE_PIN14_PORTREG	GPIOD_PDOR
#define CORE_PIN15_PORTREG	GPIOD_PDOR
#define CORE_PIN16_PORTREG	GPIOD_PDOR
#define CORE_PIN17_PORTREG	GPIOD_PDOR

#define CORE_PIN0_PORTSET	GPIOA_PSOR
#define CORE_PIN1_PORTSET	GPIOA_PSOR
#define CORE_PIN2_PORTSET	GPIOA_PSOR
#define CORE_PIN3_PORTSET	GPIOA_PSOR
#define CORE_PIN4_PORTSET	GPIOA_PSOR
#define CORE_PIN5_PORTSET	GPIOB_PSOR
#define CORE_PIN6_PORTSET	GPIOB_PSOR
#define CORE_PIN7_PORTSET	GPIOC_PSOR
#define CORE_PIN8_PORTSET	GPIOC_PSOR
#define CORE_PIN9_PORTSET	GPIOC_PSOR
#define CORE_PIN10_PORTSET	GPIOC_PSOR
#define CORE_PIN11_PORTSET	GPIOC_PSOR
#define CORE_PIN12_PORTSET	GPIOC_PSOR
#define CORE_PIN13_PORTSET	GPIOC_PSOR
#define CORE_PIN14_PORTSET	GPIOD_PSOR
#define CORE_PIN15_PORTSET	GPIOD_PSOR
#define CORE_PIN16_PORTSET	GPIOD_PSOR
#define CORE_PIN17_PORTSET	GPIOD_PSOR
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

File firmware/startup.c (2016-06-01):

/*
 * Initialization code for an FC-Boot application.
 * Copyright (c) 2013 Micah Elizabeth Scott
 *
 * Originally based on:
 *
 * Teensyduino Core Library
 * http://www.pjrc.com/teensy/
 * Copyright (c) 2013 PJRC.COM, LLC.
 *
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
 * 2. If the Software is incorporated into a build system that allows 
 * selection among a list of target devices, then similar target
 * devices manufactured by PJRC.COM must be included in the list of
 * target devices and selectable in the same manner.
 *
 * THE SOFTWARE IS PROVIDED "AS IS", WITHOUT WARRANTY OF ANY KIND,
 * EXPRESS OR IMPLIED, INCLUDING BUT NOT LIMITED TO THE WARRANTIES OF
 * MERCHANTABILITY, FITNESS FOR A PARTICULAR PURPOSE AND
 * NONINFRINGEMENT. IN NO EVENT SHALL THE AUTHORS OR COPYRIGHT HOLDERS
 * BE LIABLE FOR ANY CLAIM, DAMAGES OR OTHER LIABILITY, WHETHER IN AN
 * ACTION OF CONTRACT, TORT OR OTHERWISE, ARISING FROM, OUT OF OR IN
 * CONNECTION WITH THE SOFTWARE OR THE USE OR OTHER DEALINGS IN THE
 * SOFTWARE.
 */

#include "mk20dn64.h"

typedef void (*initFunc_t)(void);

extern unsigned long _stext;
extern unsigned long _etext;
extern unsigned long _sdata;
extern unsigned long _edata;
extern unsigned long _sbss;
extern unsigned long _ebss;
extern unsigned long _estack;
//extern unsigned long _flexram_begin;
//extern unsigned long _flexram_end;
extern initFunc_t __init_array_start;
extern initFunc_t __init_array_end;

extern int main (void);
void ResetHandler(void);
void _init_Teensyduino_internal_(void);


void fault_isr(void)
{
	while (1) {
		// keep polling some communication while in fault
		// mode, so we don't completely die.
		if (SIM_SCGC4 & SIM_SCGC4_USBOTG) usb_isr();
		if (SIM_SCGC4 & SIM_SCGC4_UART0) uart0_status_isr();
		if (SIM_SCGC4 & SIM_SCGC4_UART1) uart1_status_isr();
		if (SIM_SCGC4 & SIM_SCGC4_UART2) uart2_status_isr();
	}
}

void unused_isr(void)
{
        while (1); // die
}

extern volatile uint32_t systick_millis_count;
void systick_default_isr(void)
{
    systick_millis_count++;
}

void nmi_isr(void)		__attribute__ ((weak, alias("unused_isr")));
void hard_fault_isr(void)	__attribute__ ((weak, alias("unused_isr")));
void memmanage_fault_isr(void)	__attribute__ ((weak, alias("unused_isr")));
void bus_fault_isr(void)	__attribute__ ((weak, alias("unused_isr")));
void usage_fault_isr(void)	__attribute__ ((weak, alias("unused_isr")));
void svcall_isr(void)		__attribute__ ((weak, alias("unused_isr")));
void debugmonitor_isr(void)	__attribute__ ((weak, alias("unused_isr")));
void pendablesrvreq_isr(void)	__attribute__ ((weak, alias("unused_isr")));
void systick_isr(void)		__attribute__ ((weak, alias("systick_default_isr")));

void dma_ch0_isr(void)		__attribute__ ((weak, alias("unused_isr")));
void dma_ch1_isr(void)		__attribute__ ((weak, alias("unused_isr")));
void dma_ch2_isr(void)		__attribute__ ((weak, alias("unused_isr")));
void dma_ch3_isr(void)		__attribute__ ((weak, alias("unused_isr")));
void dma_ch4_isr(void)		__attribute__ ((weak, alias("unused_isr")));
void dma_ch5_isr(void)		__attribute__ ((weak, alias("unused_isr")));
void dma_ch6_isr(void)		__attribute__ ((weak, alias("unused_isr")));
void dma_ch7_isr(void)		__attribute__ ((weak, alias("unused_isr")));
void dma_ch8_isr(void)		__attribute__ ((weak, alias("unused_isr")));
void dma_ch9_isr(void)		__attribute__ ((weak, alias("unused_isr")));
void dma_ch10_isr(void)		__attribute__ ((weak, alias("unused_isr")));
void dma_ch11_isr(void)		__attribute__ ((weak, alias("unused_isr")));
void dma_ch12_isr(void)		__attribute__ ((weak, alias("unused_isr")));
void dma_ch13_isr(void)		__attribute__ ((weak, alias("unused_isr")));
void dma_ch14_isr(void)		__attribute__ ((weak, alias("unused_isr")));
void dma_ch15_isr(void)		__attribute__ ((weak, alias("unused_isr")));
void dma_error_isr(void)	__attribute__ ((weak, alias("unused_isr")));
void mcm_isr(void)		__attribute__ ((weak, alias("unused_isr")));
void flash_cmd_isr(void)	__attribute__ ((weak, alias("unused_isr")));
void flash_error_isr(void)	__attribute__ ((weak, alias("unused_isr")));
void low_voltage_isr(void)	__attribute__ ((weak, alias("unused_isr")));
void wakeup_isr(void)		__attribute__ ((weak, alias("unused_isr")));
void watchdog_isr(void)		__attribute__ ((weak, alias("unused_isr")));
void i2c0_isr(void)		__attribute__ ((weak, alias("unused_isr")));
void i2c1_isr(void)		__attribute__ ((weak, alias("unused_isr")));
void i2c2_isr(void)		__attribute__ ((weak, alias("unused_isr")));
void spi0_isr(void)		__attribute__ ((weak, alias("unused_isr")));
void spi1_isr(void)		__attribute__ ((weak, alias("unused_isr")));
void spi2_isr(void)		__attribute__ ((weak, alias("unused_isr")));
void sdhc_isr(void)		__attribute__ ((weak, alias("unused_isr")));
void can0_message_isr(void)	__attribute__ ((weak, alias("unused_isr")));
void can0_bus_off_isr(void)	__attribute__ ((weak, alias("unused_isr")));
void can0_error_isr(void)	__attribute__ ((weak, alias("unused_isr")));
void can0_tx_warn_isr(void)	__attribute__ ((weak, alias("unused_isr")));
void can0_rx_warn_isr(void)	__attribute__ ((weak, alias("unused_isr")));
void can0_wakeup_isr(void)	__attribute__ ((weak, alias("unused_isr")));
void i2s0_tx_isr(void)		__attribute__ ((weak, alias("unused_isr")));
void i2s0_rx_isr(void)		__attribute__ ((weak, alias("unused_isr")));
void uart0_lon_isr(void)	__attribute__ ((weak, alias("unused_isr")));
void uart0_status_isr(void)	__attribute__ ((weak, alias("unused_isr")));
void uart0_error_isr(void)	__attribute__ ((weak, alias("unused_isr")));
void uart1_status_isr(void)	__attribute__ ((weak, alias("unused_isr")));
void uart1_error_isr(void)	__attribute__ ((weak, alias("unused_isr")));
void uart2_status_isr(void)	__attribute__ ((weak, alias("unused_isr")));
void uart2_error_isr(void)	__attribute__ ((weak, alias("unused_isr")));
void uart3_status_isr(void)	__attribute__ ((weak, alias("unused_isr")));
void uart3_error_isr(void)	__attribute__ ((weak, alias("unused_isr")));
void uart4_status_isr(void)	__attribute__ ((weak, alias("unused_isr")));
void uart4_error_isr(void)	__attribute__ ((weak, alias("unused_isr")));
void uart5_status_isr(void)	__attribute__ ((weak, alias("unused_isr")));
void uart5_error_isr(void)	__attribute__ ((weak, alias("unused_isr")));
void adc0_isr(void)		__attribute__ ((weak, alias("unused_isr")));
void adc1_isr(void)		__attribute__ ((weak, alias("unused_isr")));
void cmp0_isr(void)		__attribute__ ((weak, alias("unused_isr")));
void cmp1_isr(void)		__attribute__ ((weak, alias("unused_isr")));
void cmp2_isr(void)		__attribute__ ((weak, alias("unused_isr")));
void ftm0_isr(void)		__attribute__ ((weak, alias("unused_isr")));
void ftm1_isr(void)		__attribute__ ((weak, alias("unused_isr")));
void ftm2_isr(void)		__attribute__ ((weak, alias("unused_isr")));
void ftm3_isr(void)		__attribute__ ((weak, alias("unused_isr")));
void cmt_isr(void)		__attribute__ ((weak, alias("unused_isr")));
void rtc_alarm_isr(void)	__attribute__ ((weak, alias("unused_isr")));
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

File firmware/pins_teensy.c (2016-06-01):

/* Teensyduino Core Library
 * http://www.pjrc.com/teensy/
 * Copyright (c) 2013 PJRC.COM, LLC.
 *
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
 * 2. If the Software is incorporated into a build system that allows 
 * selection among a list of target devices, then similar target
 * devices manufactured by PJRC.COM must be included in the list of
 * target devices and selectable in the same manner.
 *
 * THE SOFTWARE IS PROVIDED "AS IS", WITHOUT WARRANTY OF ANY KIND,
 * EXPRESS OR IMPLIED, INCLUDING BUT NOT LIMITED TO THE WARRANTIES OF
 * MERCHANTABILITY, FITNESS FOR A PARTICULAR PURPOSE AND
 * NONINFRINGEMENT. IN NO EVENT SHALL THE AUTHORS OR COPYRIGHT HOLDERS
 * BE LIABLE FOR ANY CLAIM, DAMAGES OR OTHER LIABILITY, WHETHER IN AN
 * ACTION OF CONTRACT, TORT OR OTHERWISE, ARISING FROM, OUT OF OR IN
 * CONNECTION WITH THE SOFTWARE OR THE USE OR OTHER DEALINGS IN THE
 * SOFTWARE.
 */

#include "core_pins.h"
#include "pins_arduino.h"
//#include "HardwareSerial.h"

#if 0
// moved to pins_arduino.h
struct digital_pin_bitband_and_config_table_struct {
	volatile uint32_t *reg;
	volatile uint32_t *config;
};
const struct digital_pin_bitband_and_config_table_struct digital_pin_to_info_PGM[];

// compatibility macros
#define digitalPinToPort(pin) (pin)
#define digitalPinToBitMask(pin) (1)
#define portOutputRegister(pin) ((volatile uint8_t *)(digital_pin_to_info_PGM[(pin)].reg + 0))
#define portSetRegister(pin)    ((volatile uint8_t *)(digital_pin_to_info_PGM[(pin)].reg + 32))
#define portClearRegister(pin)  ((volatile uint8_t *)(digital_pin_to_info_PGM[(pin)].reg + 64))
#define portToggleRegister(pin) ((volatile uint8_t *)(digital_pin_to_info_PGM[(pin)].reg + 96))
#define portInputRegister(pin)  ((volatile uint8_t *)(digital_pin_to_info_PGM[(pin)].reg + 128))
#define portModeRegister(pin)   ((volatile uint8_t *)(digital_pin_to_info_PGM[(pin)].reg + 160))
#define portConfigRegister(pin) ((volatile uint32_t *)(digital_pin_to_info_PGM[(pin)].config))
#endif

//#define digitalPinToTimer(P) ( pgm_read_byte( digital_pin_to_timer_PGM + (P) ) )
//#define analogInPinToBit(P) (P)

#define GPIO_BITBAND_ADDR(reg, bit) (((uint32_t)&(reg) - 0x40000000) * 32 + (bit) * 4 + 0x42000000)
#define GPIO_BITBAND_PTR(reg, bit) ((uint32_t *)GPIO_BITBAND_ADDR((reg), (bit)))
//#define GPIO_SET_BIT(reg, bit) (*GPIO_BITBAND_PTR((reg), (bit)) = 1)
//#define GPIO_CLR_BIT(reg, bit) (*GPIO_BITBAND_PTR((reg), (bit)) = 0)

const struct digital_pin_bitband_and_config_table_struct digital_pin_to_info_PGM[] = {
	{GPIO_BITBAND_PTR(CORE_PIN0_PORTREG, CORE_PIN0_BIT), &CORE_PIN0_CONFIG},
	{GPIO_BITBAND_PTR(CORE_PIN1_PORTREG, CORE_PIN1_BIT), &CORE_PIN1_CONFIG},
	{GPIO_BITBAND_PTR(CORE_PIN2_PORTREG, CORE_PIN2_BIT), &CORE_PIN2_CONFIG},
	{GPIO_BITBAND_PTR(CORE_PIN3_PORTREG, CORE_PIN3_BIT), &CORE_PIN3_CONFIG},
	{GPIO_BITBAND_PTR(CORE_PIN4_PORTREG, CORE_PIN4_BIT), &CORE_PIN4_CONFIG},
	{GPIO_BITBAND_PTR(CORE_PIN5_PORTREG, CORE_PIN5_BIT), &CORE_PIN5_CONFIG},
	{GPIO_BITBAND_PTR(CORE_PIN6_PORTREG, CORE_PIN6_BIT), &CORE_PIN6_CONFIG},
	{GPIO_BITBAND_PTR(CORE_PIN7_PORTREG, CORE_PIN7_BIT), &CORE_PIN7_CONFIG},
	{GPIO_BITBAND_PTR(CORE_PIN8_PORTREG, CORE_PIN8_BIT), &CORE_PIN8_CONFIG},
	{GPIO_BITBAND_PTR(CORE_PIN9_PORTREG, CORE_PIN9_BIT), &CORE_PIN9_CONFIG},
	{GPIO_BITBAND_PTR(CORE_PIN10_PORTREG, CORE_PIN10_BIT), &CORE_PIN10_CONFIG},
	{GPIO_BITBAND_PTR(CORE_PIN11_PORTREG, CORE_PIN11_BIT), &CORE_PIN11_CONFIG},
	{GPIO_BITBAND_PTR(CORE_PIN12_PORTREG, CORE_PIN12_BIT), &CORE_PIN12_CONFIG},
	{GPIO_BITBAND_PTR(CORE_PIN13_PORTREG, CORE_PIN13_BIT), &CORE_PIN13_CONFIG},
	{GPIO_BITBAND_PTR(CORE_PIN14_PORTREG, CORE_PIN14_BIT), &CORE_PIN14_CONFIG},
	{GPIO_BITBAND_PTR(CORE_PIN15_PORTREG, CORE_PIN15_BIT), &CORE_PIN15_CONFIG},
	{GPIO_BITBAND_PTR(CORE_PIN16_PORTREG, CORE_PIN16_BIT), &CORE_PIN16_CONFIG},
	{GPIO_BITBAND_PTR(CORE_PIN17_PORTREG, CORE_PIN17_BIT), &CORE_PIN17_CONFIG}
};




typedef void (*voidFuncPtr)(void);
volatile static voidFuncPtr intFunc[CORE_NUM_DIGITAL];

void init_pin_interrupts(void)
{
	//SIM_SCGC5 = 0x00043F82;		// clocks active to all GPIO
	NVIC_ENABLE_IRQ(IRQ_PORTA);
	NVIC_ENABLE_IRQ(IRQ_PORTB);
	NVIC_ENABLE_IRQ(IRQ_PORTC);
	NVIC_ENABLE_IRQ(IRQ_PORTD);
	NVIC_ENABLE_IRQ(IRQ_PORTE);
	// TODO: maybe these should be set to a lower priority
	// so if the user puts lots of slow code on attachInterrupt
	// fast interrupts will still be serviced quickly?
}
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

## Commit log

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no date Add test firmware images
    [raspi.cfg]
2016-06-02 Pull in Revision A of the schematic
    [eightbyeight.brd, eightbyeight.sch]
2016-06-02 Concept design and sizing
    [60mm diamond.SLDPRT, 60mm square.SLDPRT, 60mm square.STL]
2016-06-02 Clean up label placements on PCB
    [eightbyeight.brd, eightbyeight.sch]
2016-06-21 Routing changes on PCB, cleanup
    [eightbyeight.brd, eightbyeight.sch]
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2016-06-23 Continue implementing changes from TODO
    [eightbyeight.brd, eightbyeight.sch]
2016-06-23 Finish routing accelerometer changes
    [eightbyeight.brd, eightbyeight.sch]
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2016-06-24 PCB: Add LED_OE to row driver mux enable
    [eightbyeight.brd, eightbyeight.sch]
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2016-06-25 Add LED_HS_EN. Increase number of vias on power lines
    [eightbyeight.brd, eightbyeight.sch]
2016-06-25 Finish placing power diodes and clear DRC errors
    [eightbyeight.brd, eightbyeight.sch]
2016-06-25 Add discharge LED, finish board routing!
    [eightbyeight.brd, eightbyeight.sch]
2016-06-25 Label the LEDs
    [eightbyeight.brd]
2016-06-28 Add ICN2012 design version
    [eightbyeight-ICN2012.brd, eightbyeight-ICN2012.sch]
2016-06-29 Update ICN2012 version with new accelerometer
    [eightbyeight-ICN2012.brd, eightbyeight-ICN2012.sch]
2016-06-29 Finish laying out accelerometer, minor updates to part values/reference designators
    [eightbyeight-ICN2012.brd, eightbyeight-ICN2012.sch]
2016-06-30 Update notes for RevC version
    [eightbyeight-ICN2012.sch]
2016-06-30 Update the concept design part
    [60mm diamond.SLDPRT]
2016-06-30 Add 3v and 5v todos for schematic
    [eightbyeight-ICN2012.sch]
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2016-06-30 Clean up revb schematic
    [eightbyeight.brd, eightbyeight.sch]
2016-06-30 RevB PCB (pcb/eightbyeight.brd)
    [eightbyeight.brd, eightbyeight.sch]
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2016-07-01 Update board TODOs
    [eightbyeight-ICN2012.brd, eightbyeight-ICN2012.sch, eightbyeight.brd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]
2016-07-04 Silkscreen tweaks to pcbs
    [eightbyeight-ICN2012.brd, eightbyeight-ICN2012.sch, eightbyeight.sch]
2016-07-04 Pull in bootloader from BlinkyTile, modify DFU pin, disable LED function, and change USB identifier
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2016-07-04 Half-working attempt at 12 bit spi writes (10% faster than 8 bit)
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2016-07-08 Add (nonworking) RevC design
    [eightbyeight-ICN2012.brd, eightbyeight-ICN2012.sch]
2016-07-08 Test pads in progress
    [eightbyeight.brd, eightbyeight.sch]
2016-07-08 Bugfix: bootloader now honors recovery pin state
    [bootloader.c]
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2016-07-08 Closer to RevD
    [eightbyeight.brd, eightbyeight.sch]
2016-07-08 Final RevD
    [eightbyeight.brd, eightbyeight.sch]
2016-07-09 Work in progress: LED output broken, pixels >127 wrap to next pixel
    [main.cpp, matrix.h]
2016-07-09 Clean up board silkscreen
    [eightbyeight.brd, eightbyeight.sch]
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2016-07-11 Small updates from further testing
    [eightbyeight.brd, eightbyeight.sch]
2016-07-11 Add teardrop design for RevD
    [eightbyeight-teardrop.brd, eightbyeight-teardrop.sch]
2016-07-11 Add some solidworks case designs
    [assembled case.SLDASM, blank case.sldprt]
2016-07-13 Rev E, as submitted
    [eightbyeight-teardrop.brd, eightbyeight-teardrop.sch, eightbyeight.brd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]
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2016-07-16 Matrix: fix first byte alignment
    [matrix.cpp, matrix.h]
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2016-07-16 Broken matrix code, checkpoint
    [matrix.cpp, matrix.h]
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2016-07-18 Remove nonworking INC2012 design
    [eightbyeight-ICN2012.brd, eightbyeight-ICN2012.sch]
2016-07-18 Add HRC art
    [eightbyeight.brd, eightbyeight.sch]
2016-07-21 Use correct datasheet for LEDs
2016-07-21 Add test card for PCB
    [eightbyeight-testcard.brd, eightbyeight-testcard.sch]
2016-07-21 Production silk and component values
    [eightbyeight.brd, eightbyeight.sch]
2016-07-22 Revert X/Y swap in accelerometer: Let's fix that in the code
    [mma8653.cpp]
2016-07-22 Bugfix: Set timer values properly to avoid noise at startup
    [matrix.cpp]
2016-07-24 Update test card to fit new test jig
    [eightbyeight-testcard.brd]
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2016-07-24 Update test card with proper sized holes
    [eightbyeight-testcard.brd, eightbyeight-testcard.sch]
2016-07-25 Add raspberry pi side of test card
    [raspberrypi-testcard.brd, raspberrypi-testcard.sch]
2016-07-25 Add CERH OHL license to PCB
    [eightbyeight.sch]
2016-07-25 Update testcard to fit current test jig
    [eightbyeight-testcard.brd, eightbyeight-testcard.sch]
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2016-07-26 Firmware: don't glitch ESP reset line when resetting
    [serial1.c]
2016-07-31 Update board errata
    [eightbyeight.brd, eightbyeight.sch]
2016-07-31 Update test card pcb notes
    [eightbyeight-testcard.brd, eightbyeight-testcard.sch, raspberrypi-testcard.brd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]
2016-07-31 Test software work in progress
    [raspi.cfg]
2016-08-01 Test rig test run
    [raspi.cfg]
2016-08-03 Add note about new diode to schematic
    [eightbyeight.sch]
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2016-08-03 Fix rotations in MegaDemo, add setBrightness() command
    [RGBMatrix.cpp, Rain.cpp, mma8653.cpp]
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2016-10-13 Update production instructions
    [raspberrypi-testcard.brd]
2016-10-21 Update drivers and attempt to sign them correctly.
2016-10-24 Fix interface ID in serial driver
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2016-10-24 Fix the 'default install' section of the serial driver
2016-10-25 Add battery protection circuit
    [eightbyeight.brd, eightbyeight.sch]
2016-10-25 Add seperate bleed resistor to 5V input
    [eightbyeight-teardrop.brd, eightbyeight-teardrop.sch, eightbyeight.brd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]
2016-10-25 Add TODO for resistor/cap sizes
    [eightbyeight.sch]
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2016-10-25 Fix some filename case issues
    [ArtNetReceiver.ino]
2016-10-25 Fix artnet receiver so that it at least compiles
    [ArtNetReceiver.ino]
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2016-10-26 Move production tests to 'production' folder
    [eightbyeight-testcard.brd, eightbyeight-testcard.sch, raspberrypi-testcard.brd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]
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2016-10-26 Fix reference to arduino examples
2016-10-26 Remove old concept designs
    [60mm square.SLDPRT, 60mm square.STL]
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2016-11-22 Add support for the Flaschen Taschen protocol.
    See https://github.com/noisebridge/flaschen-taschen for more info
    about the protocol.
    [FlaschenTaschenReceiver.ino, matrix.cpp, matrix.h]
2017-02-12 Replace 0402 components, add RevH notes
    [eightbyeight.brd, eightbyeight.sch]
2017-02-12 Use copper fills for 5v, battery traces
    [eightbyeight.brd, eightbyeight.sch]
2017-02-13 Replace caps and resistors
    [eightbyeight.brd, eightbyeight.sch]
2017-02-13 Teardrop trial before release
    [eightbyeight-teardrop.brd, eightbyeight-teardrop.sch]
2017-02-13 Switch to larger PTC, release RevH
    [eightbyeight-teardrop.brd, eightbyeight-teardrop.sch, eightbyeight.brd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]
2017-03-16 Add post-production feedback on PCB
    [eightbyeight.brd, eightbyeight.sch]
2017-03-17 Fix filename mismatch in ArtNetReceiver
    [Badge.cpp, RGBMatrix.cpp]
2017-03-17 Fix filename issue in ArtNetReceiver
    [ArtNetReceiver.ino, mma8653.cpp]
2017-05-29 Fix file case error
    [BlinkyDemo.ino]
2017-05-29 Revert some changes to Rain, Life
    [Rain.cpp]
2019-09-18 Add lasercut frontplate template
    [eightbyeight_template.dxf]

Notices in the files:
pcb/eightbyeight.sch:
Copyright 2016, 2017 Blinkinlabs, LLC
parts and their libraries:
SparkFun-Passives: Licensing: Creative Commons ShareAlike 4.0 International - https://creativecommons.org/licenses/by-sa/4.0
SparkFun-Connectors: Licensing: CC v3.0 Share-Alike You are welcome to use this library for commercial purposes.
